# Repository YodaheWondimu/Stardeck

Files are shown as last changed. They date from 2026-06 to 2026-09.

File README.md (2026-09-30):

# Stardeck

A minimalist cyberdeck made for a software guy to learn embedded systems, electronics, and hardware design.
Also, a project made during and for Hack Club's 2026 [Stardance Challenge](https://stardance.hackclub.com/).

[Stardance Project Page](https://stardance.hackclub.com/projects/19479)

## Hero Image

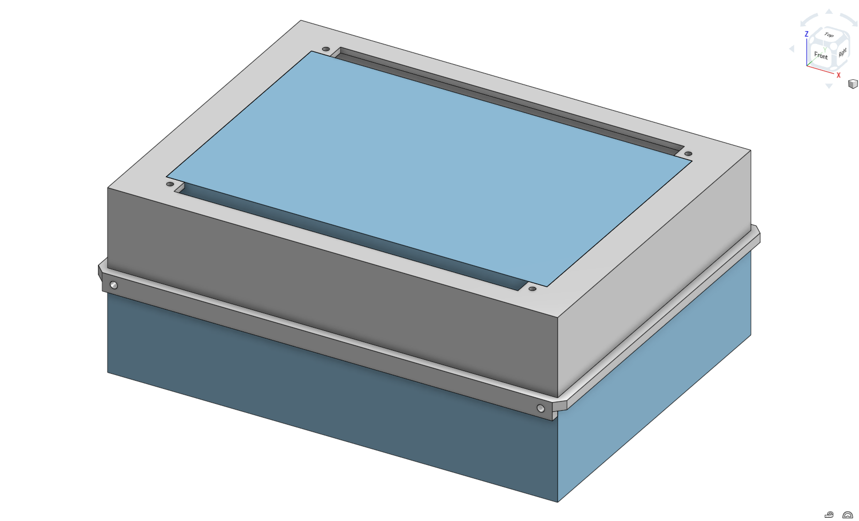
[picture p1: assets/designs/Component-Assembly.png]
Stardeck


## The Design

View the Onshape document [here!](https://cad.onshape.com/documents/8bb1ca9b7e5ac3a8ddb6398c/w/dff90e83964596d1d17b9d10/e/fb41c0251ce7e4dd570a11cb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)

## What can Stardeck do?

Once the hardware is assembled, Stardeck would be able to:
- Boot Raspberry Pi OS
- Surf the web
- Download and upload files
- Connect to external devices
- Work with a touchscreen (no mouse required!)
- Allow for further customization in the future (through the Pi's GPIO pins)

## Bill of Materials (BOM)

**Note: The Raspberry Pi 4, keyboard, and flash drive are already owned, so I currently do NOT need funding for these parts. The parts I need funding for are the ones with prices listed next to them - the display, power bank, memory card, and video cable.**

| Component | Model | Qty | Cost | Link |
|---|---|----:|-----:|---|
| Computer | Raspberry Pi 4 Model B (4GB RAM) | 1 | $0.00 | Already Owned - NOT requesting funding for |
| Display | Elecrow RC070 7-inch Touchscreen Display (1024×600) | 1 | $54.99 | [CrowPi](https://www.crowpi.cc/products/rc070-7-inch-raspberry-pi-monitor-1024x600-touchscreen-mini-hdmi-lcd-screen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) |
| Power Bank | Anker 10000mAh Portable Charger | 1 | $19.99 | [Amazon](https://www.amazon.com/Anker-Travel-Ready-Technology-High-Speed-Output%EF%BC%88Black%EF%BC%89%EF%BC%8C1pack/dp/B0D5CLSMFB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) |
| Storage | SanDisk Ultra Plus 64GB microSDXC UHS-I Memory Card | 1 | $14.00 | [Best Buy](https://www.bestbuy.com/product/sandisk-ultra-plus-64gb-microsdxc-uhs-i-memory-card/JXJ62C647Q) |
| Video Cable / Adapter | Micro HDMI to HDMI Adapter Cable (6 inch) | 1 | $3.64 | [Walmart](https://www.walmart.com/ip/Micro-HDMI-to-HDMI-Adapter-Cable-4K-60Hz-15cm-6-inch-Short-Cord-for-Raspberry-Pi-5-4-Camera-Tablet-HDTV/19994810413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) |
| Keyboard | Existing USB Keyboard | 1 | $0.00 | Already owned |
| Flash Drive | Existing 128GB USB Flash Drive | 1 | $0.00 | Already owned |

**Total Project Cost (USD): $92.62**

## How Stardeck Works

As a cyberdeck, what Stardeck has that laptops from big tech may not have is a simple digital experience. With no bloatware or ads pushed onto the user, your device is truly yours. Of course, the planned device for now is a minimum viable product focusing on what Stardeck can do to join the cyberdeck club.

The parts that'll be used consist of:
- Raspberry Pi 4 Model B
- Elecrow Touchscreen Display
- Anker Portable Charger
- microSDXC Memory Card
- microHDMI to HDMI Adapter Cable
- Keyboard
- Flash Drive

The parts will be organized together to fit into a 3D printed enclosure of my design. To understand how Stardeck works, we can look into the purposes of each part and how they interact. The Raspberry Pi was chosen to handle all of Stardeck's computing tasks because it was capable of running a dedicated OS, connecting to the outside world (Internet, Bluetooth, USB-A), and intuitively receiving power without turning Stardeck into a gaming rig. The touchscreen display from Elecrow keeps the enclosure simple with the added bonus of running Stardeck independent of a mouse. The usage of two different memory sources, the memory card and the flash drive, abstracts away logistics/"stats for nerds" for the user's sanity - the memory card can hold OS and system files for the Pi while the flash drive can hold personal files and executables for the user.

These are the parts that I'm using, but what about the part that I'm designing - the enclosure? I went with a two-piece clamshell design for its elegant ease of use. After adding alignment lips to help with nesting the top half onto the bottom shoebox-style, I continued adding physical features as necessary. For example, the mounting rails on the bottom half are the Raspberry Pi's stepstool; they keep the Pi near the middle of Stardeck so it can connect to all the other parts easily. A battery tray also makes up the bottom half to keep the battery pack from sliding all around. When I was figuring out which side to place the battery tray into, I realized how annoying it would be to nudge the battery pack under the mounting rails, so I chose the side opposite to it on the enclosure floor to save myself from crying later. As for actually keeping these parts' order, I used threaded bosses as my holes in the mounting rails, top half, and alignment lips to cooperate with screws that'll mount the Raspberry Pi, screen, and enclosure halves respectively. After months of designing/wrestling around parts I didn't have, the main lesson I've learned is that the toil of predicting and fixing hardware problems before they show themselves to you is just one step prior to the fun part I'm hoping for: getting a usable Stardeck to work IRL.

## Acknowledgements

The [Stardance Challenge](https://stardance.hackclub.com/) is what pushed me to take an idea and turn it into something unmistakably mine this summer. Go check them, and [Hack Club](https://hackclub.com/), out! This wouldn't have been possible without their guidance, support, and honest feedback.

Thanks to [HTM Workshop's KiCAD tutorial playlist](https://www.youtube.com/playlist?list=PLUOaI24LpvQPls1Ru_qECJrENwzD7XImd) for walking me through how KiCAD works. Just knowing KiCAD existed was a game changer for how I viewed the project, even if I ended up using Onshape to give my idea some shape. The big three used in my project were KiCAD for initial schematics, draw.io for architecture diagrams and notes, and Onshape for the physical CAD that got Stardeck out of the phase of "that would be nice to have. Oh well..."

**AI Usage Declaration:** I regularly used ChatGPT as a learning resource while making Stardeck, since it was able to introduce libraries to me that I wasn't familiar with, find relevant Featurescripts for certain problems in Onshape, and monitor consistency between my port map in draw.io and my modeled connections in Onshape. However, all major decisions that characterized Stardeck were made by me.

Want to learn more about Stardeck?
I've got key design notes in the [`docs`](docs) folder.
There's day-to-day progress in my [`JOURNAL`](JOURNAL.md), too!

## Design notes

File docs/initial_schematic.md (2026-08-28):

# Initial Schematic

_Note: This is simply a system schematic to understand how components in the cyberdeck will interact with one another, paired with a packaging study to understand how much space each part takes up in our chosen arrangement. Nothing too crazy for now._

With ideation for designs in place, it's easy to jump into the technical details first. However, that's for some time later. This document focuses on the abstracted interactions between the power, the Raspberry Pi (I chose to go with a Raspberry Pi 4B), the screen, and the keyboard. After we figure out these interactions, we can take note of dimensions and (hopefully?) get a physical representation of our current parts onto Onshape so we can design a starting case. The starting question was:

**What parts will Stardeck consist of, and how do they interact with one another?**

Here's what I managed to identify about the major subsystems and their relationships through investigation.

## Questions Answered
The cyberdeck consists of four primary subsystems:
- Power
- Computer
- Input
- Output

## System Schematic (acting as our initial plan)
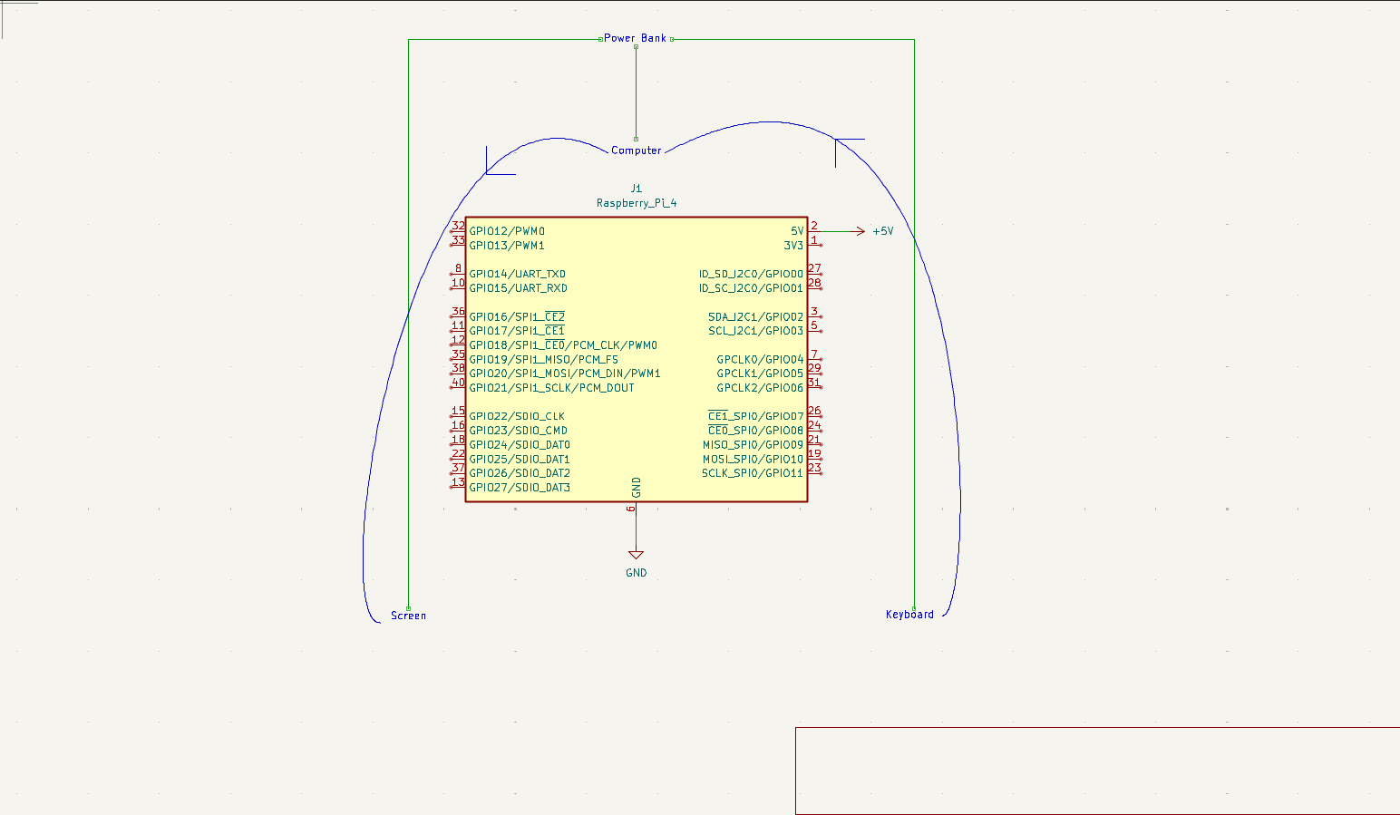
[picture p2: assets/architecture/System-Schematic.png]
System Schematic


## Descriptions:
- The power subsystem provides energy to all the other subsystems. This is the cornerstone of Stardeck.
- The computer acts as the central controller. It manages the actions of input and output.
- The keyboard serves as the primary input device. Makes sense - typing will be the main source of input as other input sources (coming through extra USB ports for other devices) can be figured out later, especially if the display is touchscreen.
- The display serves as the primary output device. It shows you what's going on.

## Open Questions
- Which display to buy?
- How large should the battery be?
- Integrated keyboard or external keyboard?
- Approximate enclosure dimensions?

I was able to follow along with this intuitively. After this, I looked into many cyberdeck designs available publicly (r/cyberdeck was particularly helpful) and decided on a compact, tablet-like cyberdeck.

This will consist of a screen inserted into the front face, with the Raspberry Pi and power bank mounted inside the shelled enclosure behind it. This is the most efficient design to aim for as of right now since we're only aiming to boot it up for this version. In future versions, we can make the screen rotate to face you laptop-style for a better feel.

## Packaging Study Findings

These were the initial, "best guess" dimensions inside the placeholder based on guesswork:

(All 3D dimensions listed are in the form length x width x height.)

- **Case**: 230 mm x 160 mm x 40 mm, 
_(with a cut-out opening on the top face to make room for the inserted screen.)_

- **Screen**: 200 mm x 120 mm x 15 mm

- **Raspberry Pi 4B**: 90 mm x 60 mm x 25 mm

- **Power Bank**: 110 mm x 70 mm x 20 mm

The initial screen placeholder was too big to match the intended size.

The original placeholder measured approximately 200 mm × 120 mm, resulting in a diagonal of ~233 mm (~9.2 inches). However, the intended display size is 7 inches. The placeholder was revised to:

- **Screen (7")**: 155 mm x 87 mm x 15 mm,

yielding a diagonal measurement consistent with a 7-inch display.

This change made me more conscious about lowering the enclosure footprint in other ways, too, so I looked into the accuracy of the rest of the designs.

The case size appears sufficient to fit all components based on the placeholder assembly, since everything fit neatly inside of it (or inserted onto it, in the screen's case). The Raspberry Pi placeholder was intentionally sized slightly larger than the actual board to account for cable clearance, tolerances, and mounting considerations. As for the battery pack, though, I haven't selected anything specific just yet. Because of this, the battery pack's placeholder dimensions are based on estimates and should be updated once a specific battery model is selected. Speaking of selection, note that the battery dimensions are preliminary estimates based on a typical 10,000 mAh USB power bank and should be updated after choosing our final power source (something rechargeable from Anker, perhaps).

With these in mind, here was the placeholder assembly used for the packaging study:

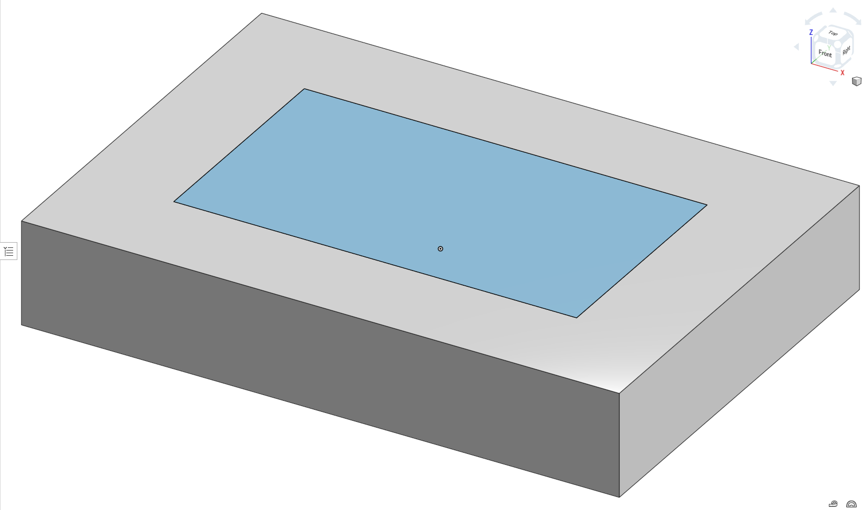
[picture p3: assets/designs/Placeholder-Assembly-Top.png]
Placeholder Assembly (Top)


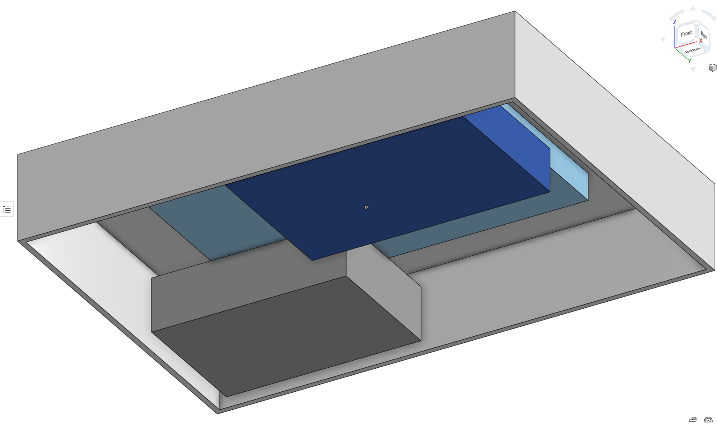
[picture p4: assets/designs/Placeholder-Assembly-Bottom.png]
Placeholder Assembly (Bottom)


So far, the parts we will be using seem to interact with each other clearly and fit into one coherent assembly. For next steps, we'll determine how the selected components will interface with one another and refine this system diagram into a more detailed schematic.

God bless you,

^ Yodahe

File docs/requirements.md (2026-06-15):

# Requirements

These are what the Stardeck needs before considered complete.
After these are fulfilled, we can always improve it then, but these are our priorities.
Afterwards, we can decorate it, give it a cooler design, etc

## Functional Requirements
- Must boot Linux
- Must run Python
- Must be battery-powered
- Must have keyboard input

## Non-Functional Requirements
- Portable
- Durable enough for backpack use
- 3D printable

## Constraints
- Student budget (can't spend too much on this)
- First cyberdeck (haven't done much hardware work before)
- Limited electronics experience (Arduino starter kit, that's it)

## Success Criteria

Stardeck v0.1 is considered complete when:

- Linux boots successfully
- Python programs can be executed
- Device operates from battery power
- Keyboard input functions correctly
- Device can be transported in a backpack

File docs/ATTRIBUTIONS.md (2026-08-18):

# CAD Attributions

Some component models used in Stardeck's detailed assembly were made by third parties and are included as reference geometry for dimensions, packaging, and assembly.

## Raspberry Pi 4 Model B

- **Model:** Raspberry Pi 4 Model B
- **Creator:** [Pyro_Industries](https://www.printables.com/@pyro)
- **Source:** https://www.printables.com/model/727545-raspberry-pi-4
- **License:** CC0 / Public Domain
- **Use:** Reference geometry for the Raspberry Pi 4 Model B in Stardeck's detailed assembly.
- **Modifications:** None

## 7-inch Display

- **Model:** Elecrow RC070 7-inch Touchscreen Display (1024x600)
- **Creator:** Elecrow
- **Source:** https://www.crowpi.cc/products/rc070-7-inch-raspberry-pi-monitor-1024x600-touchscreen-mini-hdmi-lcd-screen
- **License:** Not stated on the source page
- **Use:** Reference model used to verify display placement and enclosure clearances.
- **Modifications:** Added mounting holes matching those of the real component to coordinate screen mounting with the top half of the enclosure.

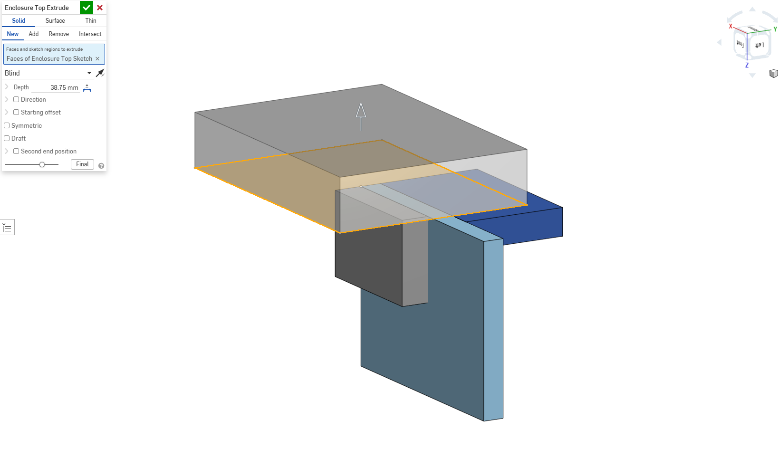
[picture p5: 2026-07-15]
assets/designs/Enclosure-Top-Extrude.png

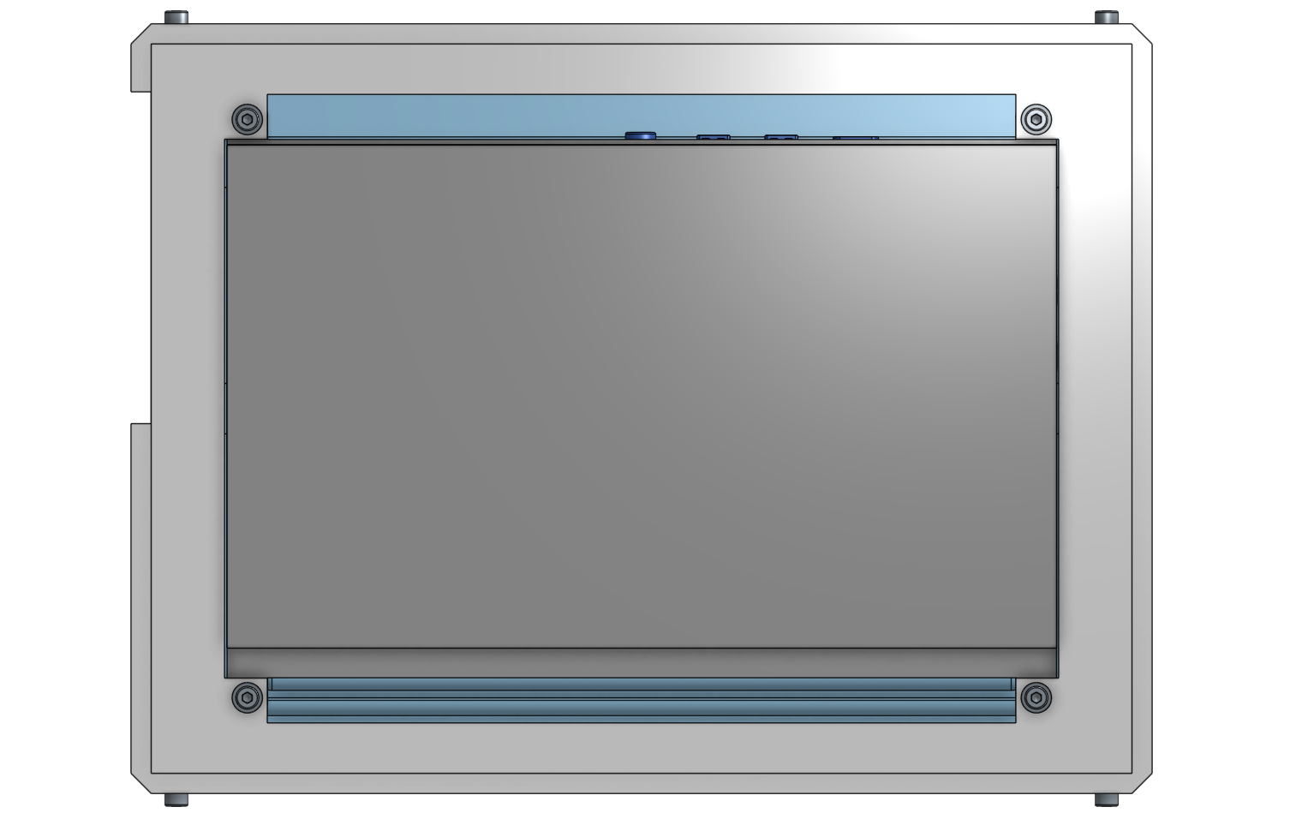
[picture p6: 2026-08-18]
assets/designs/Revised-Top-View.png

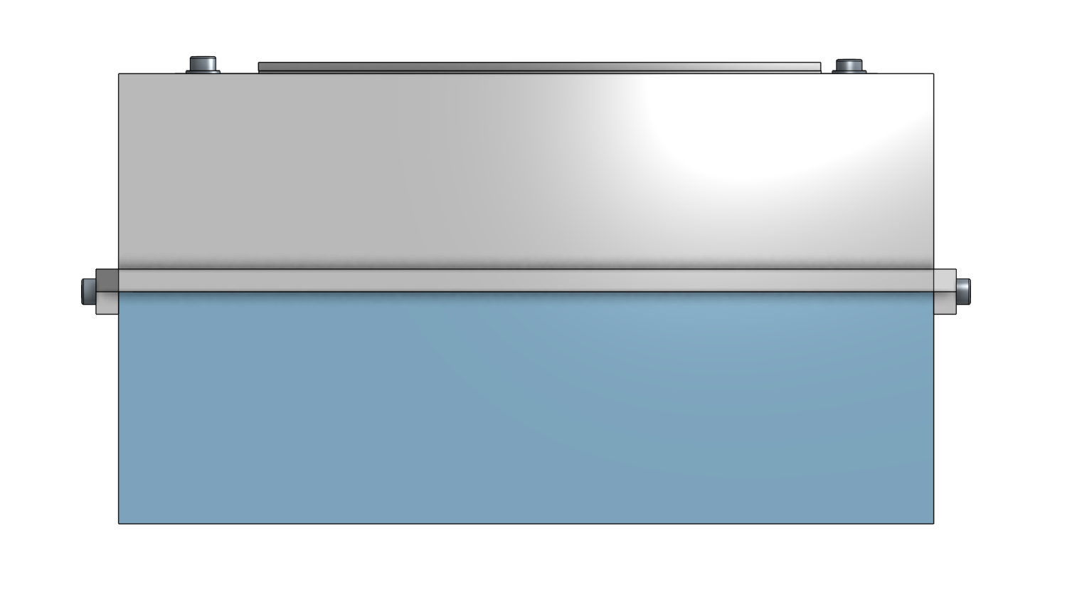
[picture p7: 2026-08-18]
assets/designs/Revised-Side-View.png

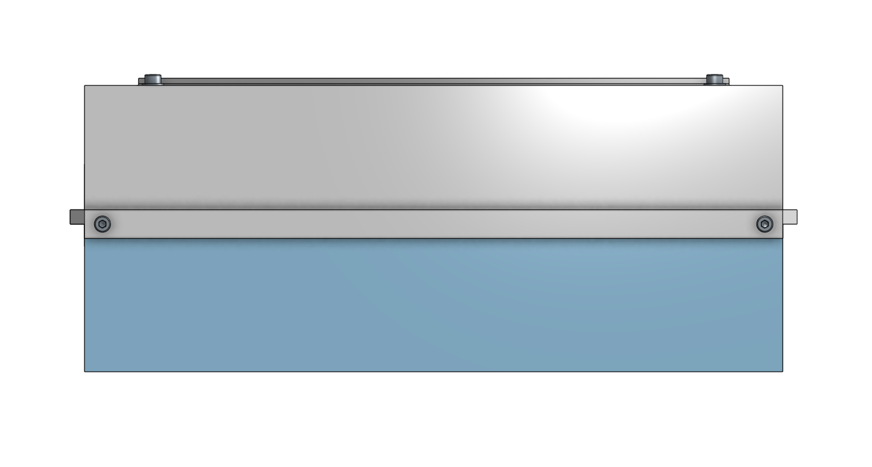
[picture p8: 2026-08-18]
assets/designs/Revised-Front-View.png

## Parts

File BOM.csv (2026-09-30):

Component | Model | Qty | Cost | Link
Computer | Raspberry Pi 4 Model B (4GB RAM) | 1 | 0.00 | Owned - NOT requesting funding for
Display | Elecrow RC070 7-inch Touchscreen Display (1024x600) | 1 | 54.99 | https://www.crowpi.cc/products/rc070-7-inch-raspberry-pi-monitor-1024x600-touchscreen-mini-hdmi-lcd-screen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
Power Bank | Anker 10000mAh Portable Charger | 1 | 19.99 | https://www.amazon.com/Anker-Travel-Ready-Technology-High-Speed-Output%EF%BC%88Black%EF%BC%89%EF%BC%8C1pack/dp/B0D5CLSMFB
Storage | SanDisk Ultra Plus 64GB microSDXC UHS-I Memory Card | 1 | 14.00 | https://www.bestbuy.com/product/sandisk-ultra-plus-64gb-microsdxc-uhs-i-memory-card/JXJ62C647Q
Video Cable / Adapter | Micro HDMI to HDMI Adapter Cable (6 inch) | 1 | 3.64 | https://www.walmart.com/ip/Micro-HDMI-to-HDMI-Adapter-Cable-4K-60Hz-15cm-6-inch-Short-Cord-for-Raspberry-Pi-5-4-Camera-Tablet-HDTV/19994810413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
Keyboard | Existing USB Keyboard | 1 | 0.00 | Owned
Flash Drive | Existing 128GB USB Flash Drive | 1 | 0.00 | Owned
Total Project Cost (USD) |  | 1 | 92.62

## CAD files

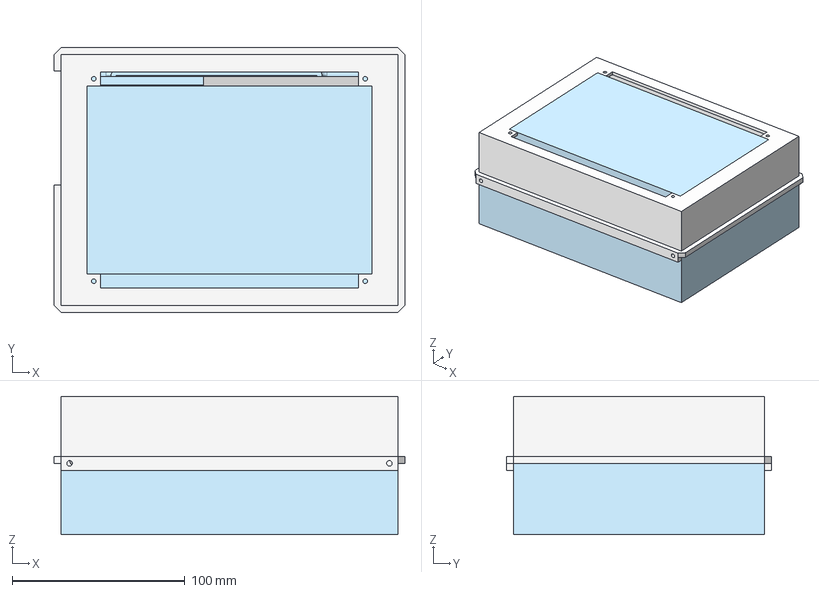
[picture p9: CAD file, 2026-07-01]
cad/Component-Assembly.step
203.0 x 153.0 x 80.0 mm

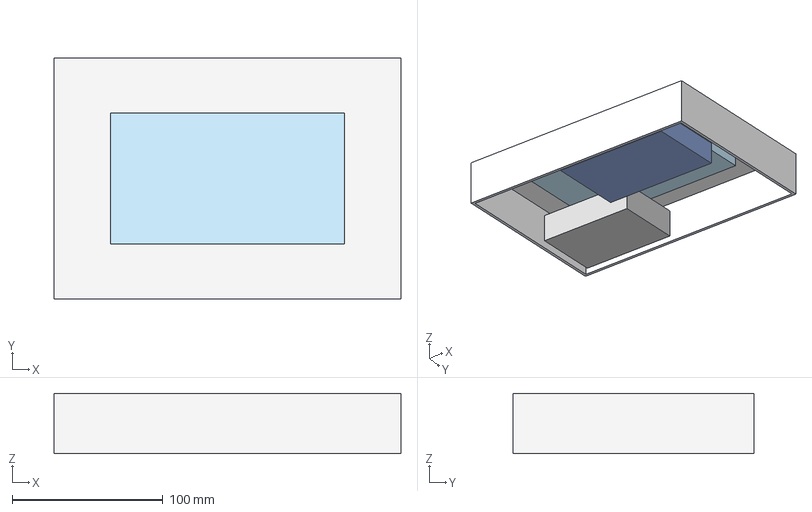
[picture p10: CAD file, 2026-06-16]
cad/Placeholder-Assembly.step
230.0 x 160.0 x 40.0 mm
Battery Block
Screen Block
Pi Block
Enclosure Base

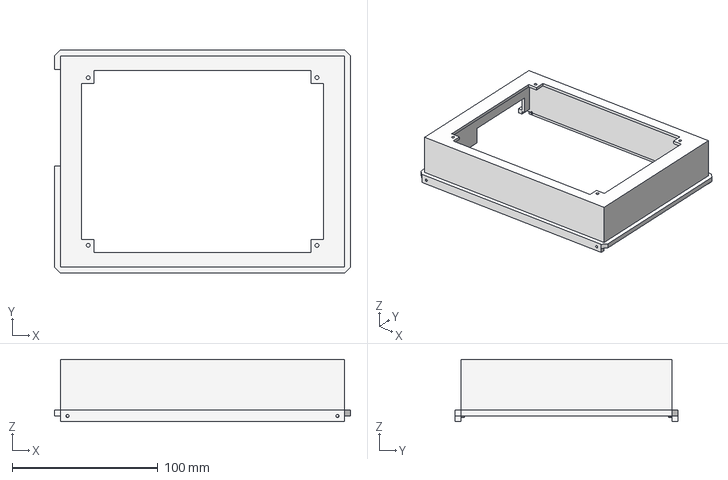
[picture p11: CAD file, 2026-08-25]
cad/Enclosure-Top-Revised.step
203.0 x 153.0 x 42.8 mm

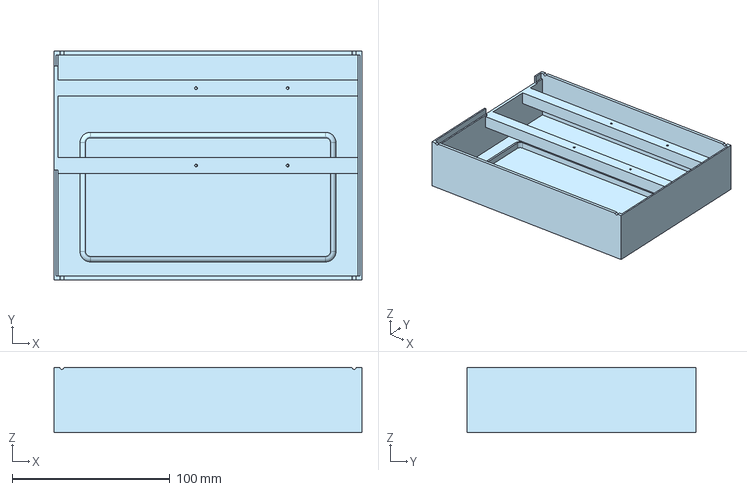
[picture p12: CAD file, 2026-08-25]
cad/Enclosure-Bottom-Revised.step
195.0 x 145.0 x 41.2 mm

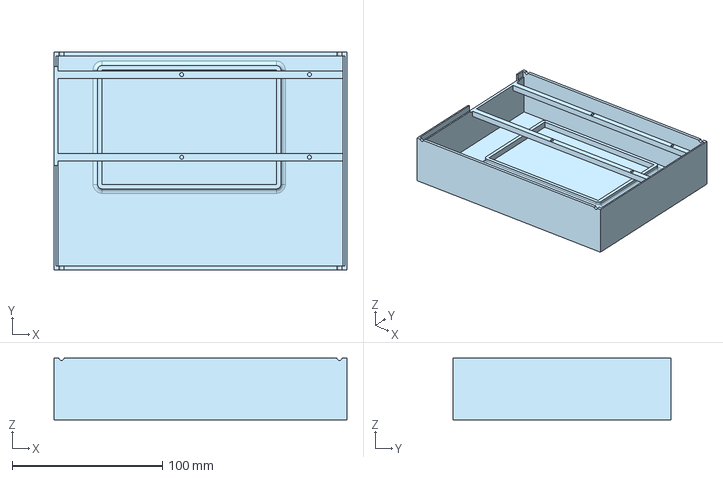
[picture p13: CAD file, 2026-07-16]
cad/Enclosure-Bottom.step
195.0 x 145.0 x 41.2 mm

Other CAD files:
cad/Enclosure-Top.step
cad/Component-Assembly.stl
cad/Enclosure-Bottom-Revised.3mf
cad/Enclosure-Bottom-Revised.stl
cad/Enclosure-Bottom.3mf
cad/Enclosure-Bottom.stl
cad/Enclosure-Top-Revised.3mf
cad/Enclosure-Top-Revised.stl
cad/Enclosure-Top.3mf
cad/Enclosure-Top.stl
cad/Placeholder-Assembly.stl

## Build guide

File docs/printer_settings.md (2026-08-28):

# Printer Settings

Hey there! This document is a place to store my print settings. Due to the open-source nature of Stardeck, you can already find those by looking in [`../assets/designs`](../assets/designs/), where you'll see the `.3mf` project files used to print the enclosure. This document is your reference point if a slicer import does not preserve every setting, so if you're here after that happened, you're welcome!

## Printer

**Printer model:** Creality Hi

**Nozzle diameter:** 0.4 mm

## Filament

**Material:** PLA

**Nozzle temperature:** 210 °C (default profile)

**Bed temperature:** 60 °C

**Cooling:** Default PLA profile

## Print

**Slicer:** Creality Print 7.x

**Layer height:** 0.2 mm

**Initial layer height:** 0.2 mm

**Wall loops:** 2

**Top shell layers:** 4

**Bottom shell layers:** 4

**Infill density:** 15%

**Sparse infill pattern:** Rectilinear

**Internal solid infill pattern:** Monotonic

**Outer wall speed:** 200 mm/s

**Inner wall speed:** 300 mm/s

**Sparse infill speed:** 270 mm/s

**Internal solid infill speed:** 250 mm/s

**Top surface speed:** 200 mm/s

**Travel speed:** 300 mm/s

**Initial layer speed:** 50 mm/s

**Seam position:** Aligned

**Supports:** Enabled

**Support style (Tree):** Default

**Build plate:** Smooth PEI (High Temperature Plate)

**Build plate adhesion (Brim, etc.):** None

## Helpful Tips

When printing each shell, orient your print so that the biggest face is touching the printbed. (Print orientation photos demonstrate this below.) For the bottom shell, keep the bottom-side face down, and for the top shell, keep the screen-side face down.

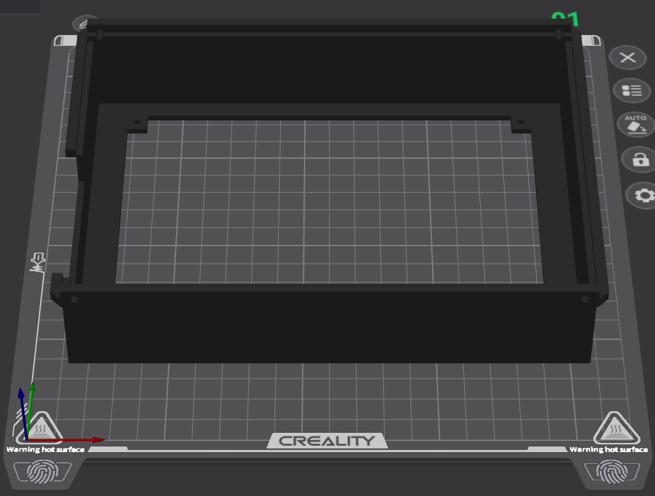
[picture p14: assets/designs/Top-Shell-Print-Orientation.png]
Print Orientation (Top)


- Approximate Print Time (Top Shell): 4 Hours, 48 Minutes
- Filament Usage (Top Shell): ~102.74 g

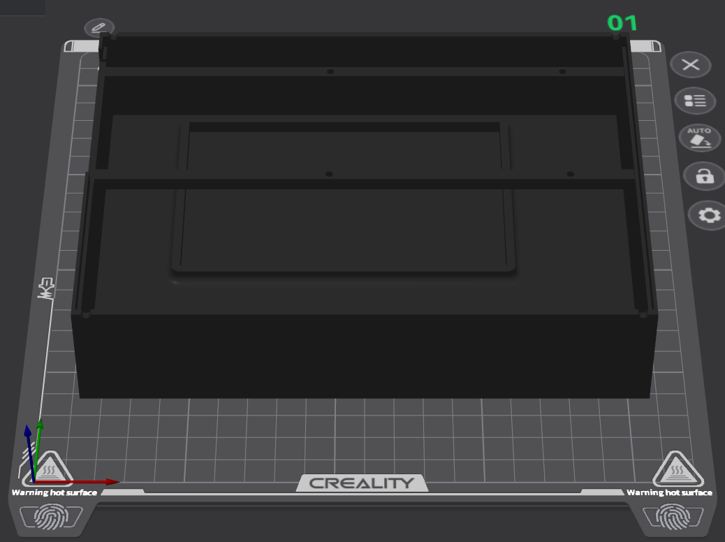
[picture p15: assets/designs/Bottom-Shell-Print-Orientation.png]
Print Orientation (Bottom)


- Approximate Print Time (Bottom Shell): 4 Hours, 36 Minutes
- Filament Usage (Bottom Shell): ~144.18 g

After setting up these orientations, it's recommended to add automatic tree supports to support the floating cantilever (from the mounting rails) in the bottom shell and the overhanging alignment lips in the top shell.

If you're using the included `.3mf` project files, no need to worry - these orientations and supports should already be preserved.

## Note

The accompanying `.3mf` project files preserve the print orientation, support placement, and slicer settings used to produce the printable models in this repository, including the first physical enclosure documented in [`../JOURNAL.md`](../JOURNAL.md).

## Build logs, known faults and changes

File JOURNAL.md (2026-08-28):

# JOURNAL

Welcome to the JOURNAL! This document holds the timeline, decisions, and designs that have trademarked the work I've put into Stardeck thus far. Here are the summaries from each date.

## 2026-06-15
This is where it starts. The project in question was a cyberdeck, we knew that much for sure. But what takes me to a cyberdeck exactly? What are the goals? What's the minimum possible device that would count as a cyberdeck? Would this be too strenuous for a self-declared software guy to do? There was only one way to find out.

To start doing the thing, I wanted to at least know what the goals were. I reasoned the goal into this: _Build the ugliest possible cyberdeck and submit it to Stardance, including what I learned from building it._ Probably not the nicest maker if I'm calling my own projects ugly, but the idea is that aesthetics and twist-giving, defining features can wait until I can actually figure out how to get a cyberdeck booting first. We can add more features and aesthetics later, but something that boots is our main priority, similar to how you need to know how to make a cheese pizza before making one with toppings. In other words, the goal is to get a cyberdeck working, and the Minimal Viable Product (MVP) is a cyberdeck that works.

Oh, I also chose what I'll use for the cyberdeck's brain - a Raspberry Pi. The specific model will be a Raspberry Pi 4B with 4GB of RAM, and it packs a lot of computing efficiency compared to what I used to think Single-Board Computers could do. This thing can boot an OS, interact with components, connect using Internet and Bluetooth, and more - plus, the Pi is a clear favorite of first-time cyberdeckers (whatever you call them).

_TL;DR:_
- Defined project goals and MVP.
- Selected Raspberry Pi as the compute platform.

**Time Spent This Session: 0 Build Hours (Research Only)**

## 2026-06-16
KiCAD is a tool that allows you to create electrical schematics for components such as custom Printed Circuit Boards (PCBs). I like to think of it as Onshape, but for electricity. One good thing that comes from this is that I'm able to use the basics to visualize components and pins at the very least, even if I don't use a PCB for the initial cyberdeck. Wiring concepts were coming through, and I got to thinking about what makes a cyberdeck a cyberdeck.

Initial Concept

Okay, so about KiCAD...it was helpful, but not exactly the tool I needed. KiCAD is the tool that guides you through schematics, PCBs, circuits, and other feats of electrical engineering. That's great and all, but it wasn't exactly the thing that I was going for all the way because my component connections were occurring on the component level rather than the electrical level. I knew that I would have to plan out how every component would fit together, and so I started an initial packaging study exclusively using a placeholder for only a few parts. This helped me think of the general shape of the cyberdeck before committing to working on more of the packaging study, and I went with a tablet-style cyberdeck for the first iteration.

Placeholder Assembly (Top)

Placeholder Assembly (Bottom)

With these in place, I published my very first devlog to Stardance to hear what others thought so far. I tried to write in a formal tone like I tend to do for replicable public work, but we'll see how the tone of voice fits in.

_TL;DR:_
- Learned KiCAD basics.
- Drew initial wiring concepts on KiCAD.
- Determined a custom PCB wasn't needed for v1.
- Posted Devlog #1 to Stardance.

**Time Spent This Session: ~1.5 Hours**

## 2026-06-17
I had to figure out how I was going to plan everything out if KiCAD wasn't necessarily my best bet. That's when I was looking into tools online and found draw.io - an open-source drawing platform that allows you to create diagrams for development workflows. This really fit what I was going for, and after learning the basics, I worked through the first few elements, which represented the components of Stardeck.

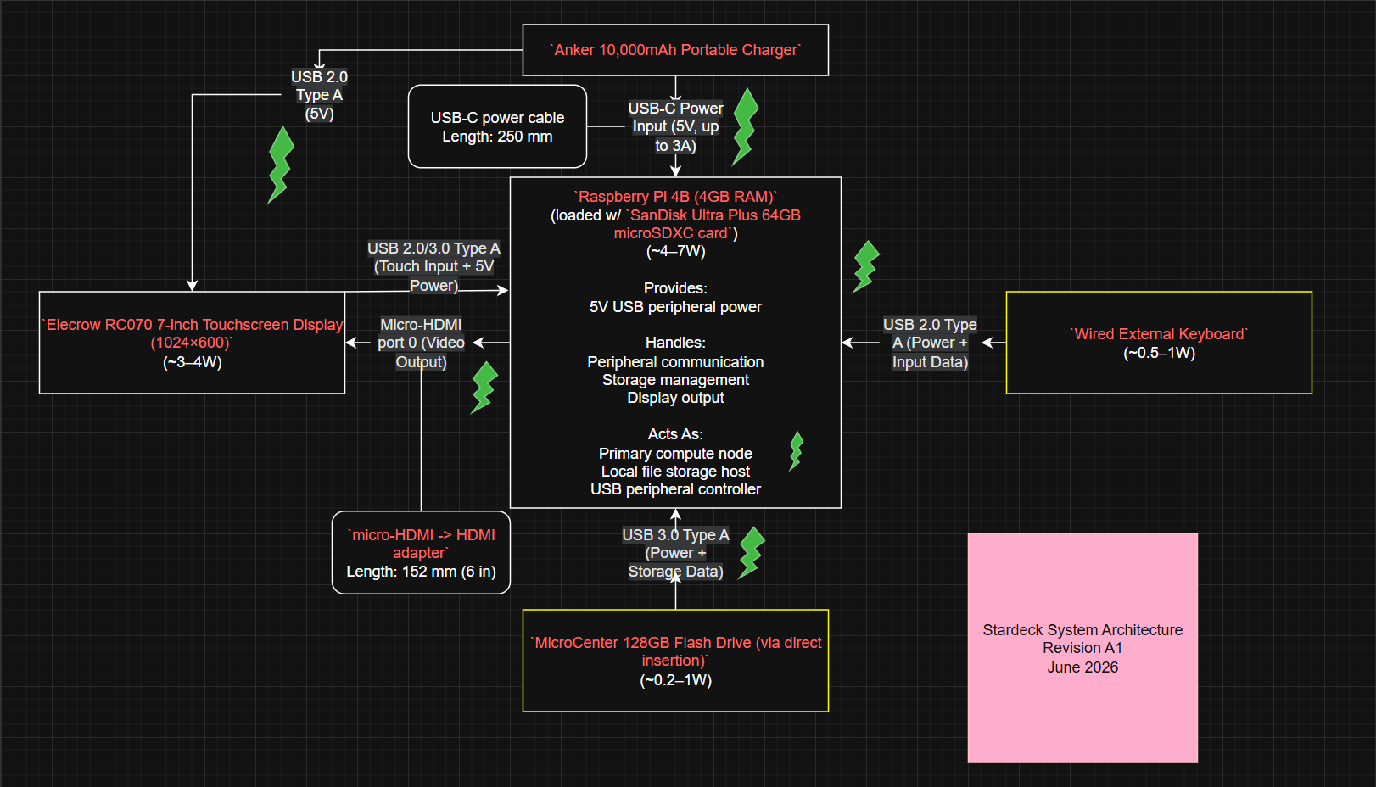
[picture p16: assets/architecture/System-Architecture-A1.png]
Wiring Diagram Revision A1


_TL;DR:_
- Learned how to use draw.io for diagrams.
- Started making a wiring diagram with draw.io.

**Time Spent This Session: ~0.5 Hours**

## 2026-06-23

Yeah, my tone of voice wasn't hitting the right notes with the audience I had. My devlog seemed so distant from the audience compared to others I've seen on Stardance. Some even considered the devlog to be AI writing, even though that was far from the truth. I was confused. If everyone saw my work right there, why did it still seem like a robot was talking to them? That's when I realized that seeing my work wasn't enough when that was all they could see. My audience wanted to hear about the journey and the steps in between, not just the ending. That's when I committed to keeping future devlogs story-focused so that I wouldn't receive any doubts as to if I was the one on the keyboard.

When looking through my display options, I needed something that would have enough functionality to pack into a cyberdeck with the goal of making it work. On top of that, I later realized that my display also needed to boot with everything else. Adapters should be included if necessary, our port maps should align with our long-term goals, and our screen had to be mountable. With these in mind, I chose a 7-inch touchscreen display from Elecrow, which supported the Raspberry Pi and could fit into the enclosure I had in mind.

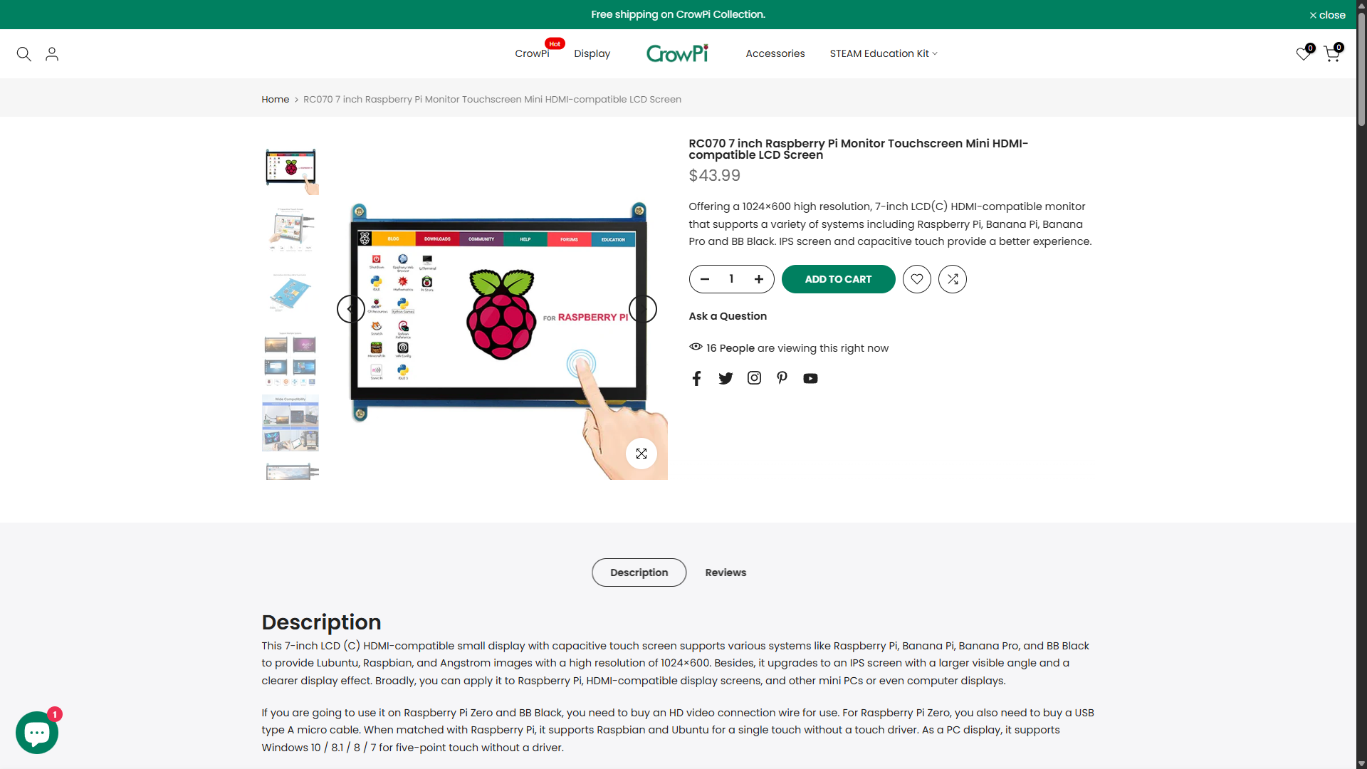
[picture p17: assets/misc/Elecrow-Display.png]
Elecrow Display


I used these same design ideas for starting my Bill of Materials (BOM) which can tell Hack Club which parts I need when it's time to get funded. I was able to pick out essentials such as a MicroSD card (system storage), a power bank/battery (distributes power to everything else), and more.

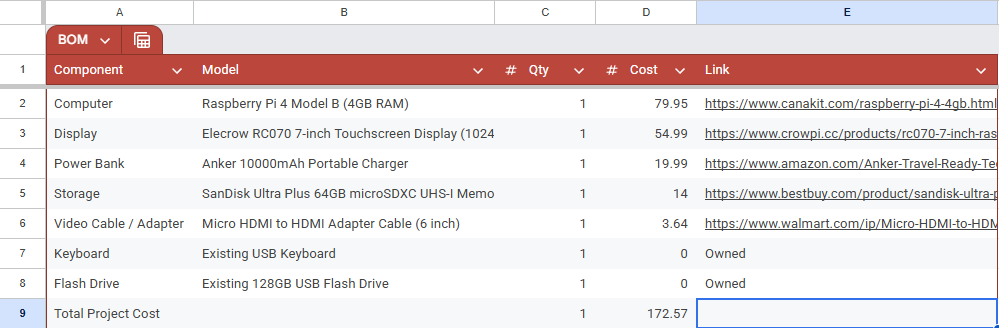
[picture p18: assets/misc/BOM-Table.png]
Bill of Materials


Another great thing that came with finding these components online was that they came with dimensions that reflected just how long, wide, or tall something was, which was bound to help me as I set out to gather info that may be useful for a packaging study.

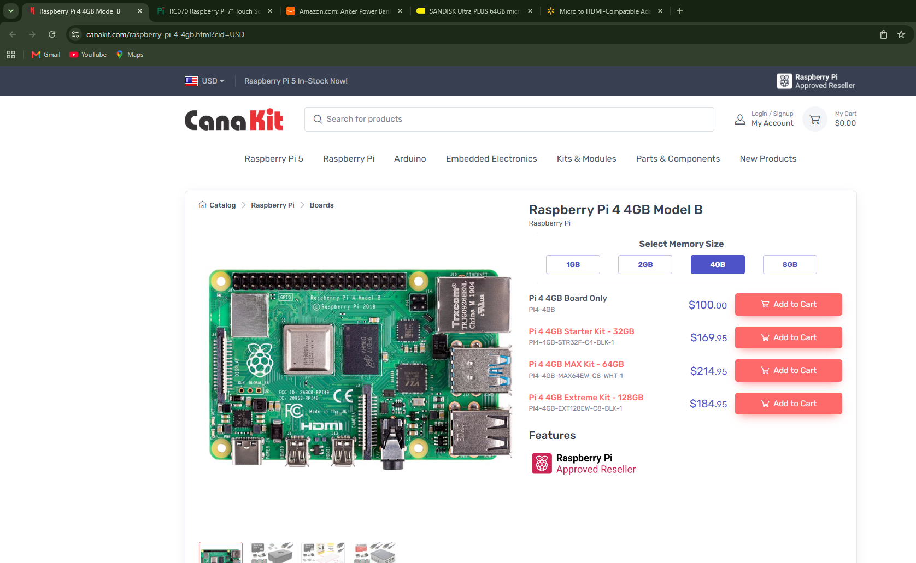
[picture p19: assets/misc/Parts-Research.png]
Researching Parts


_TL;DR:_
- Reworked my devlog writing style.
- Compared display options.
- Started BOM.
- Estimated component dimensions.

**Time Spent This Session: ~1.5 Hours**

## 2026-06-24

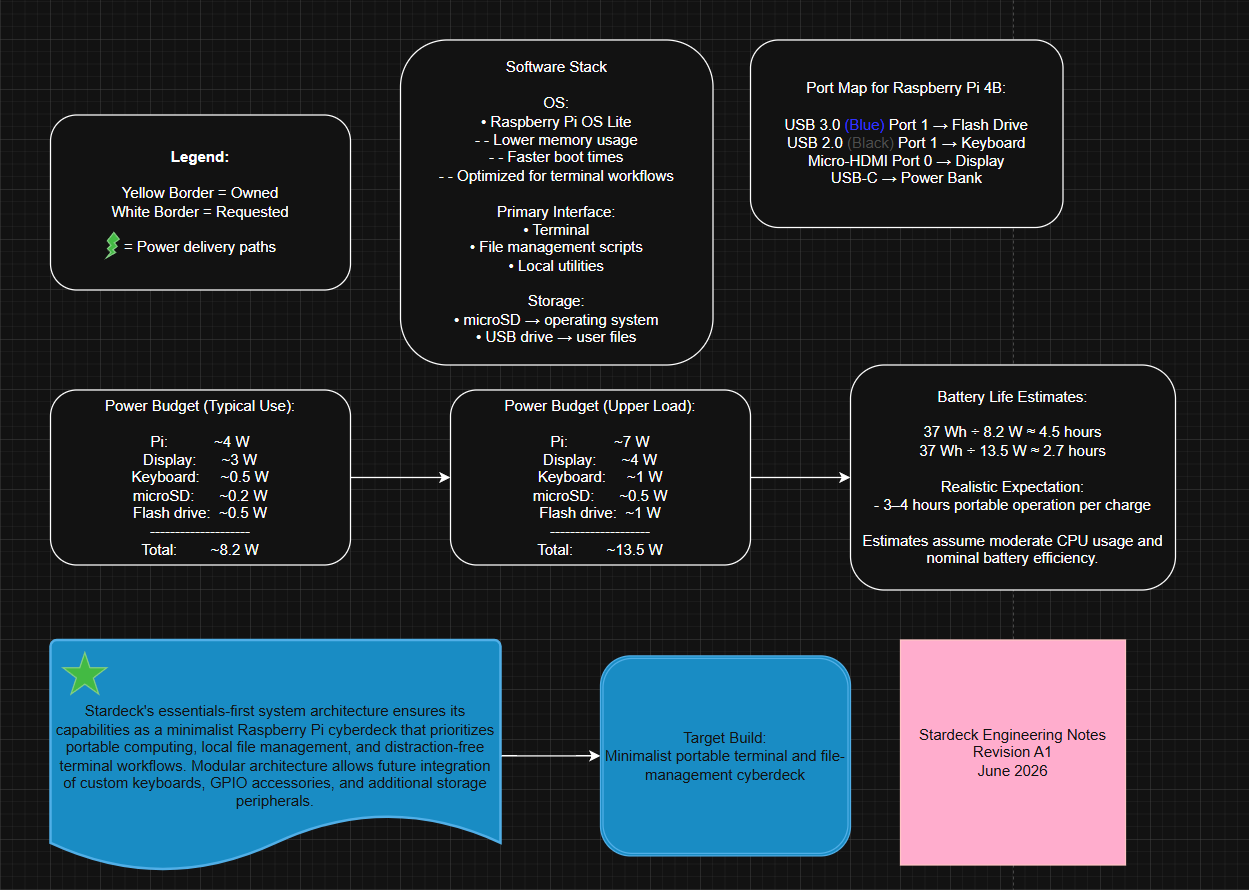
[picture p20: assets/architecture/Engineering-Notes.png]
Engineering Notes


Time for the real packaging study. These are involving parts that should work together surprisingly well if the wiring diagram stays true to its word.

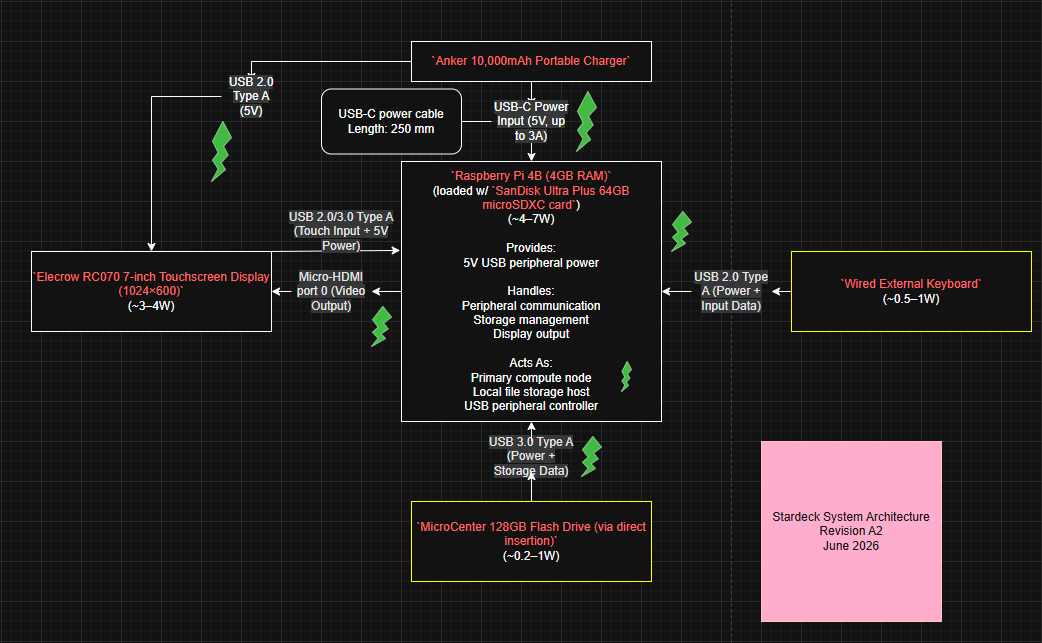
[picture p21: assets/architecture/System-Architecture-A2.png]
Wiring Diagram Revision A2


I started by modeling a few of the individual parts - screen, enclosure, Pi, and more. Luckily, the model's didn't need to have too much time put into them during the packaging study because all I needed to do was model each part as a rectangular prism of the same dimensions and model around that. Once my parts were accounted for, I used the "simple" component models to choose how big my enclosure needed to be. This was a big tradeoff to account for in the project because I wanted to have enough space for every component, but I didn't want to waste filament or create something bulky that doesn't fit the portable size requirement I had in mind.

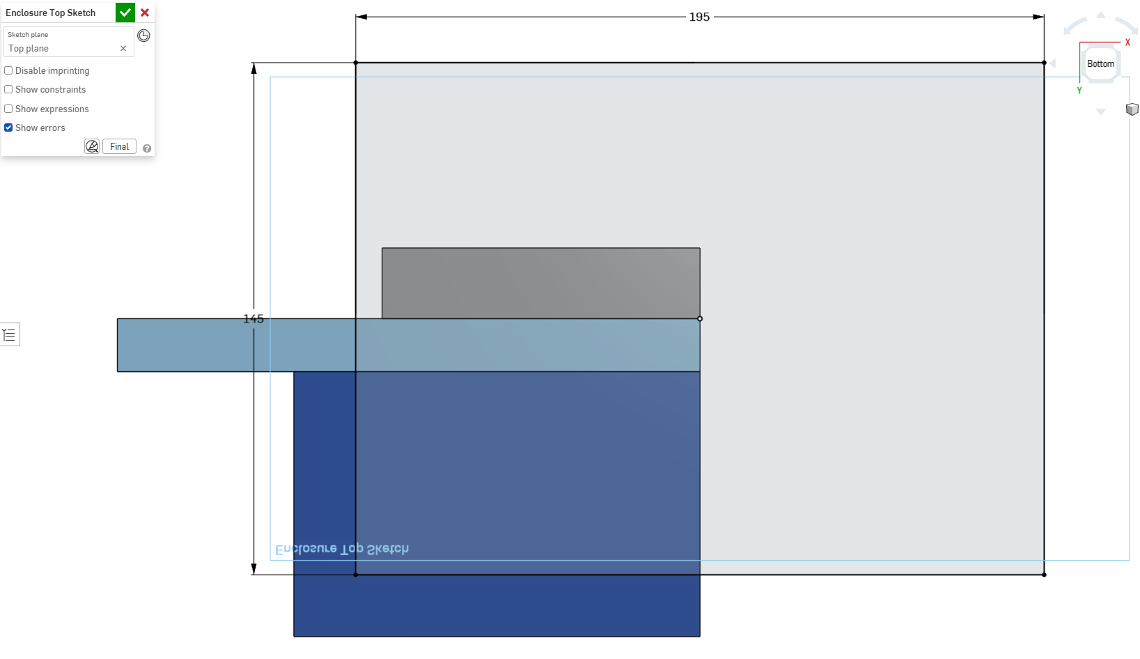
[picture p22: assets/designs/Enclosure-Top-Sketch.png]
Enclosure Length and Width


The enclosure sizing I came up with was great - 145 mm by 195 mm, with a depth of 38.75 mm. I also shelled out one of the faces to create 2.5 mm walls and cut out an opening for the display to sit in. After a lot of thought into how the system would act, it was time to figure out how the system should look.

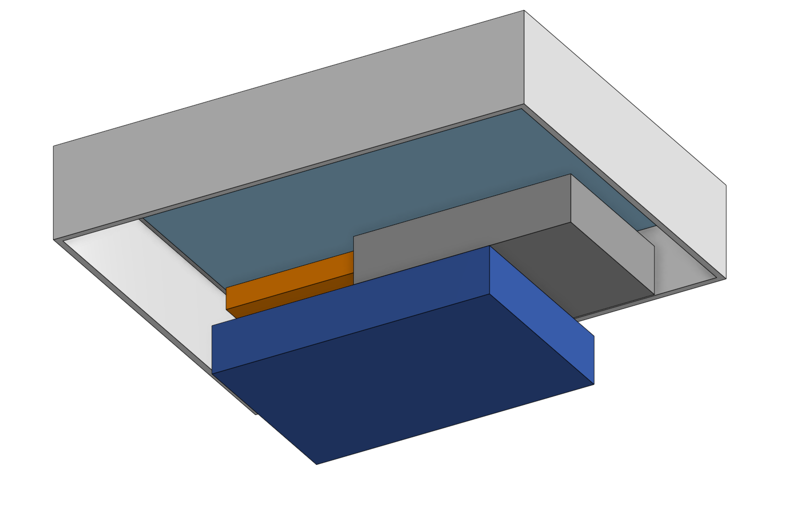
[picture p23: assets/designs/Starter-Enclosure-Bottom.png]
Starter Enclosure (Bottom)


_TL;DR:_
- Began packaging study in Onshape.
- Created simplified component models.
- Tested enclosure sizing.

**Time Spent This Session: ~0.5 Hours**

## 2026-06-28

My design was coming together. I modeled other parts such as my existing USB flash drive to provide additional storage to the user and cables that would depict possible cable routes from part to part. Once I got the internal parts done, I was thinking to myself about how every part would be physically built, until I realized that that would be close to impossible. The reason for this was that my enclosure was essentially just a plastic box with the lid missing. That's when I went through some decision-making to choose the enclosure that would solve this problem, highlighted below as one of my design decisions.

After the decision was made, I settled on a clamshell design that utilized two shells, top and bottom, to make up two different halves of the enclosure.

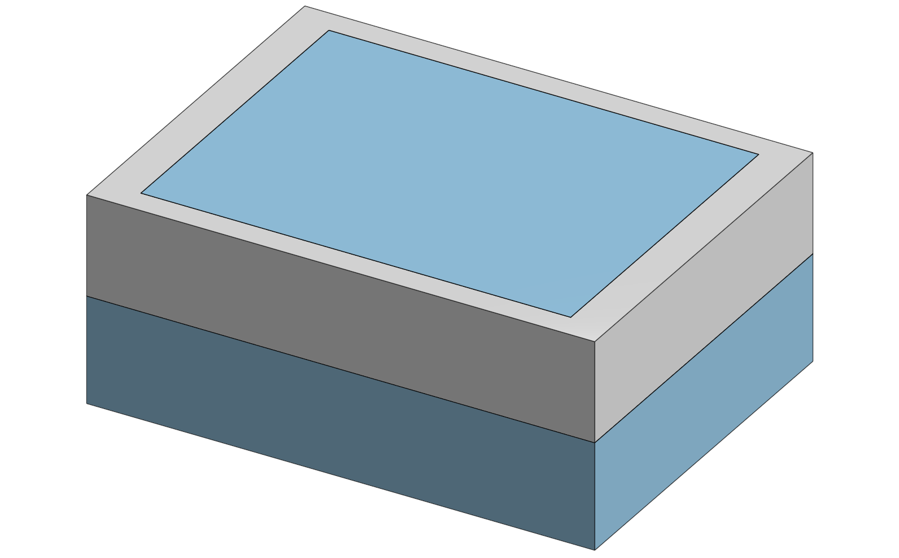
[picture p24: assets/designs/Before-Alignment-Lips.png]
Starter Clamshell


Complemented by alignment lips to keep the halves level with each other when screwing them together later, I had a real design coming up. The next real objectives were to turn my design into something that others could understand, since some parts of my enclosure still seemed like they could use more documentation.

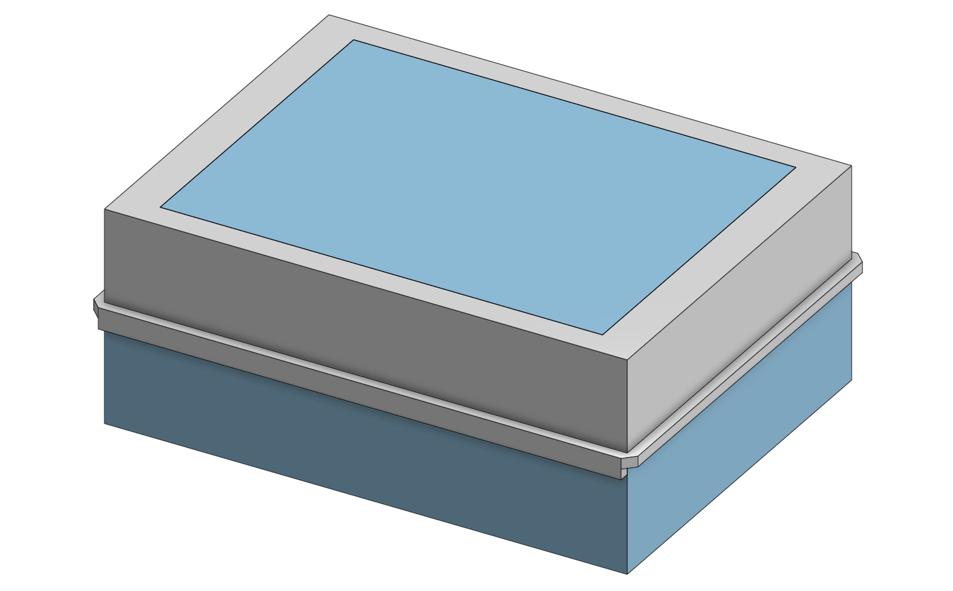
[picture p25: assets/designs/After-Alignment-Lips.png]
Alignment Lips


Furthermore, it's not like the Raspberry Pi was going to levitate in the real build. After understanding that the Pi doesn't come with flying powers, I designed simple mounting rails thanks to the design decision outlined at the bottom, which served as a working solution. I also knew of the Raspberry Pi's mounting capabilities (such as M2.5 screw holes in its corners) and how those capabilities would work well with the mounting rails in the long run.

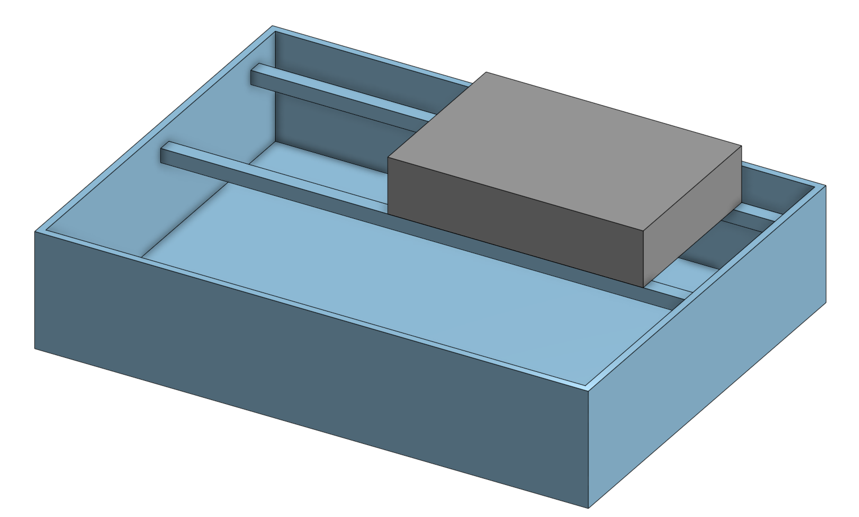
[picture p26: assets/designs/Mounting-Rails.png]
Mounting Rails


_TL;DR:_
- Switched from a one-piece enclosure to a clamshell design.
- Added alignment lips after evaluating assembly.
- Added mounting rails to support the Pi.

**Time Spent This Session: ~1.5 Hours**

## 2026-06-29

Just some polish to make things easier later. I checked over part sizes, compared them to the real components, and looked through how I could keep them in place according to what I could find online about each part. This let me learn lots of neat features about each of my parts. For example, why is the size of the screen diagonal about 8 inches when Elecrow says the screen diagonal is 7 inches? The answer: border features. The screen came with features on the border such as mounting holes and ports that required the actual diagonal measured across the surface in Onshape's perspective to be bigger than that of the screen only. Most, but not all, of that face belongs to what will actually be displayed. Nuances like this were picked up well, but apart from the research, many tweaks were made in sizing and positioning to make assembly easier later, with the main tweak being a battery tray. Another design decision below walks you through how I chose my battery mounting method, and the battery tray won over mounting straps because of its simplicity and intuition; it's like putting square pegs into square holes.

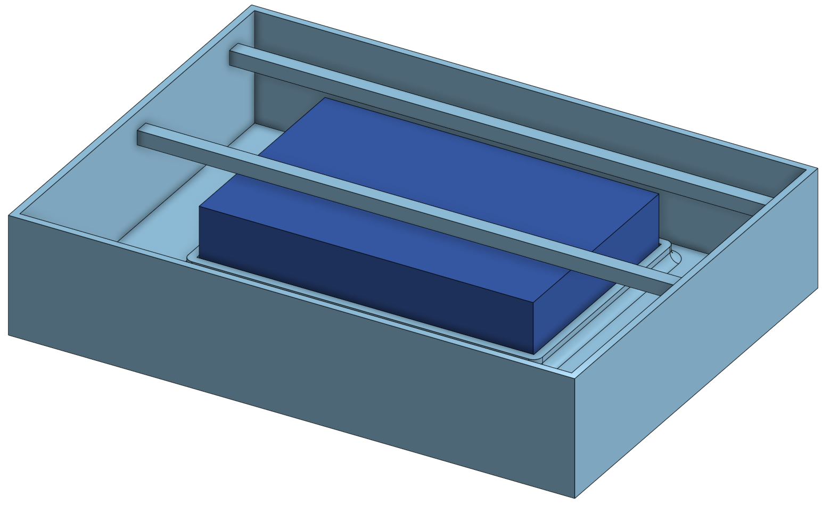
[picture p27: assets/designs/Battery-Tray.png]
Battery Tray


_TL;DR:_
- Polished wiring presentation quirks at the assembly level.
- Added battery tray to keep the battery stable.

**Time Spent This Session: ~0.5 Hours**

## 2026-06-30

Wait, so the parts _don't_ attach by themselves? I thought so. Good thing I thought of adding screw holes to anywhere that keeping parts from falling or sliding really mattered. I added screw holes in both enclosure halves to keep internals stable once I have the finished build,

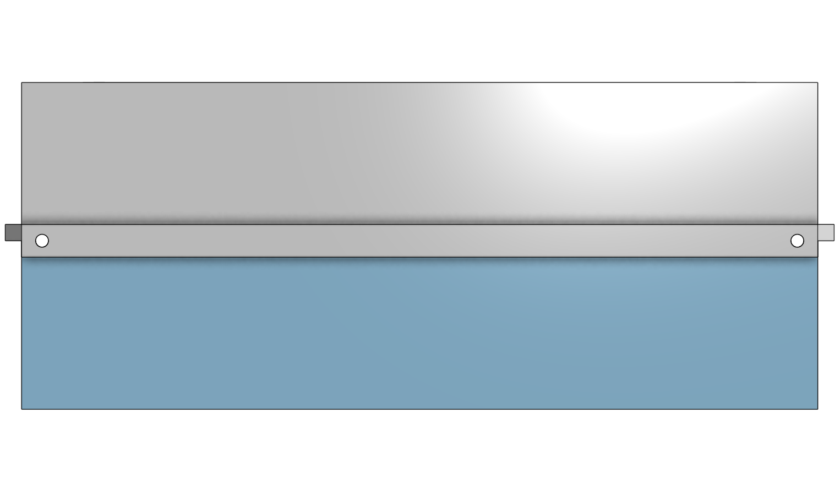
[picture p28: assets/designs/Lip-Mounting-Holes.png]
Lip Mounting Holes


on the mounting rails to keep the Pi in place,

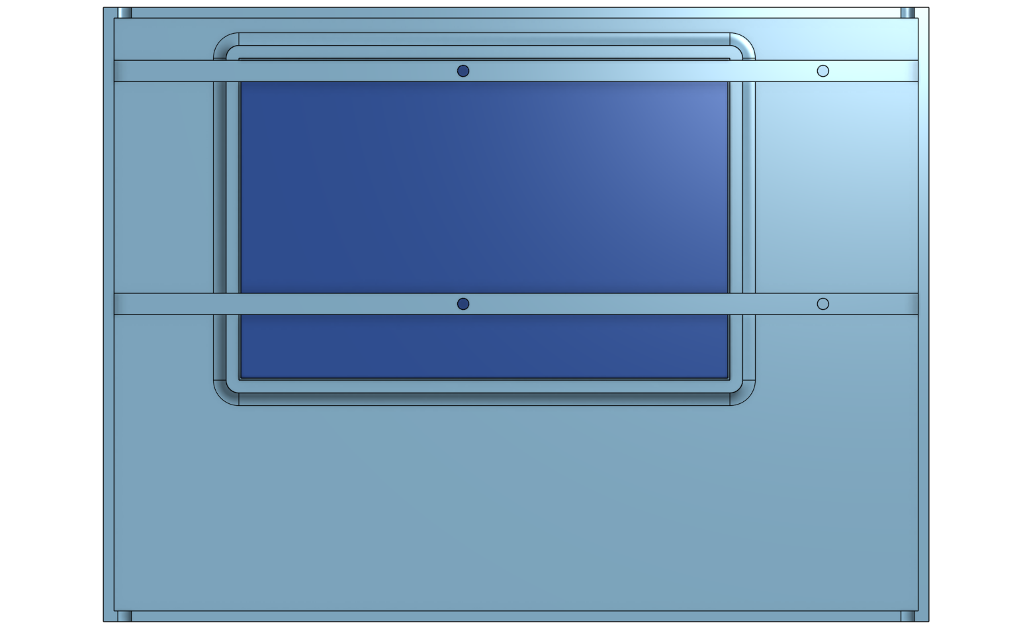
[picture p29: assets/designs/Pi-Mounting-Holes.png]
Pi Mounting Holes


and on the corners of the display cutout to mount the display in place.

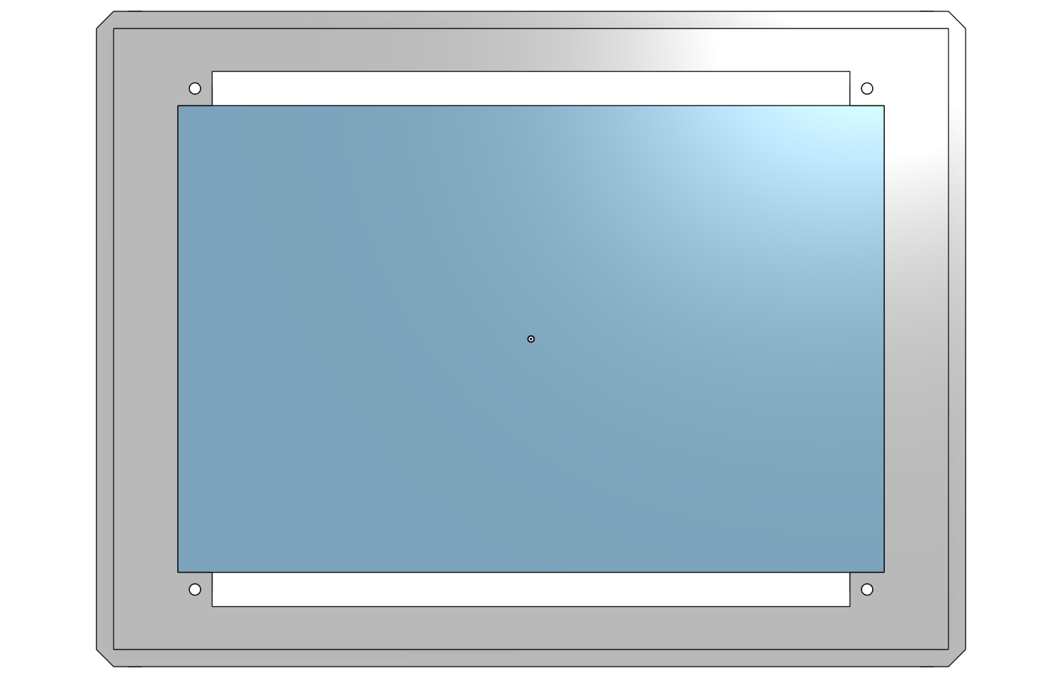
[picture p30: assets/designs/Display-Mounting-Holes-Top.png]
Display Mounting Holes (Top)


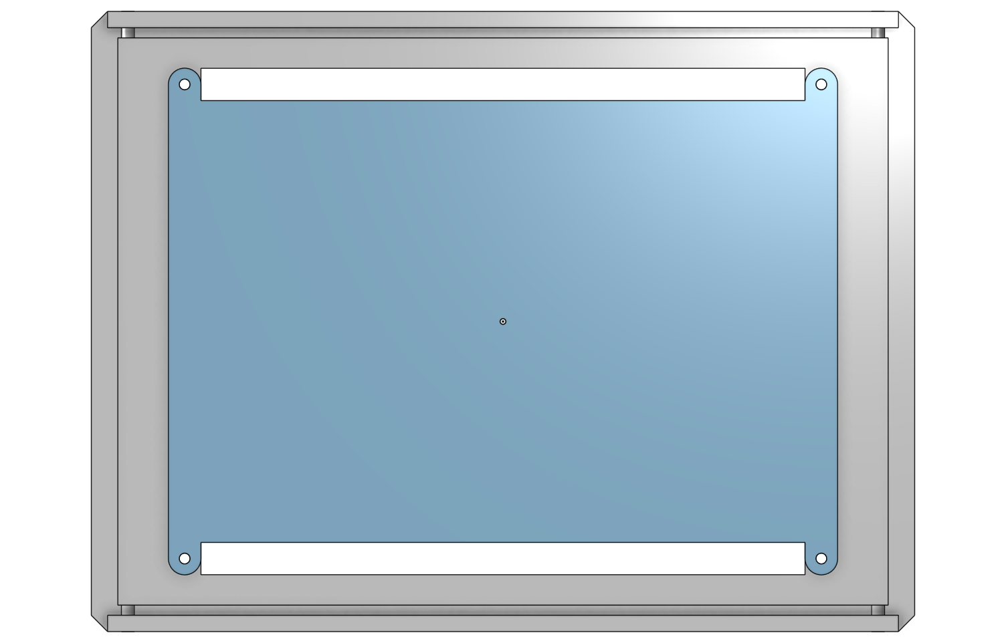
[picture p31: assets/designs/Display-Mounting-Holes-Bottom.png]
Display Mounting Holes (Bottom)


I used M2.5 holes for the Pi and display, along with M3 holes for the enclosure halves.

For documentation to work out later, I created two exploded views to tell the story of my assembly. The first one is a regular exploded view - showing the front, top, and side profiles - and another is a layered sort of exploded view - a front view of exploded parts that explains how every component is grouped and layered internally, which explains the tablet-like shape very well!

### Exploded View Part Numbers

1. Top Enclosure
2. Bottom Enclosure
3. Raspberry Pi
4. Battery Pack
5. Screen
6. Flash Drive
7. Alignment Lip
8. Battery Tray
9. Mounting Rails

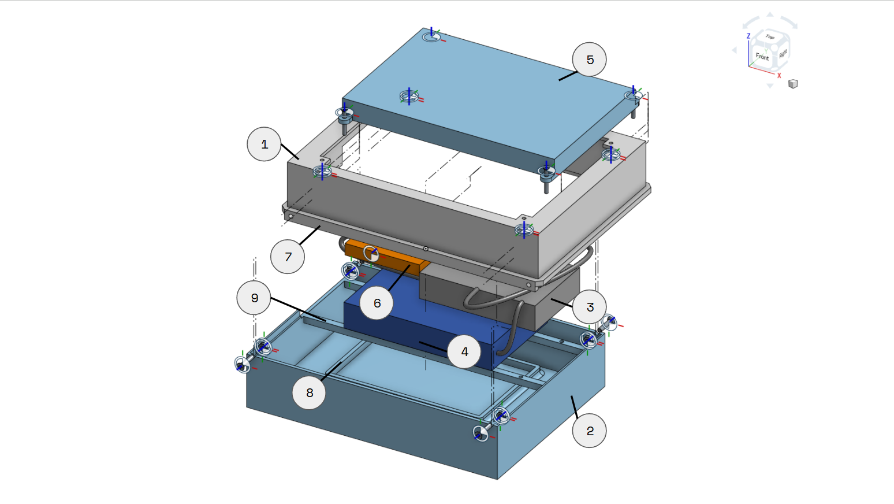
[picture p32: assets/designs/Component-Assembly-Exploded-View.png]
Exploded View (Total)


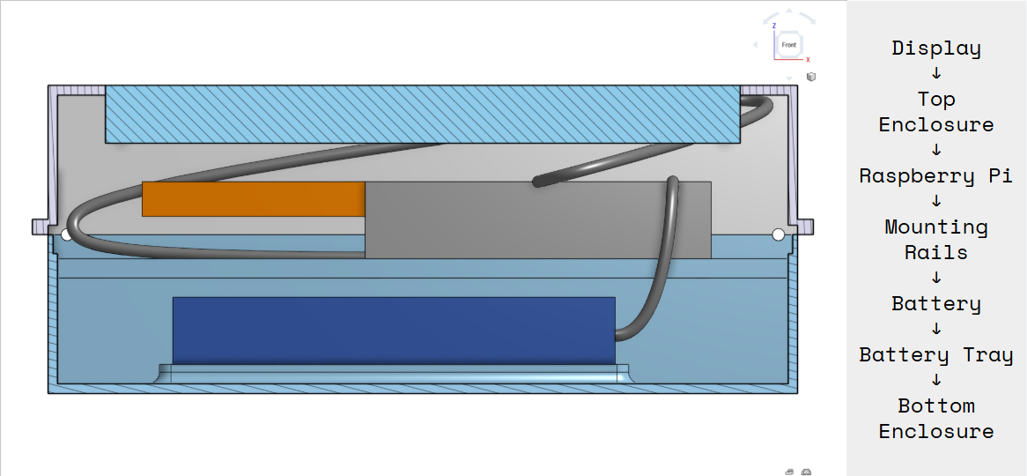
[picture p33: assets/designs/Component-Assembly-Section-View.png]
Exploded View (Layered/Section)


_TL;DR:_
- Added clearance holes to mount parts via screws and nuts later.
- Created two exploded assemblies (one a total assembly, another a layered assembly).

**Time Spent This Session: ~2 Hours**

## 2026-07-01

At this point, I was celebrating away. I started off with labeling my main exploded view, which made me realize just how much of my enclosure is truly done right now. I was surprised to find that all the components fit together in one enclosure, but when looking at the Pi in specific, I visualized the USB ports near where the flash drive was modeled. That's when I finally realized that the outside world still exists and I still need a way to connect external devices to the Pi when the enclosure is sealed off.

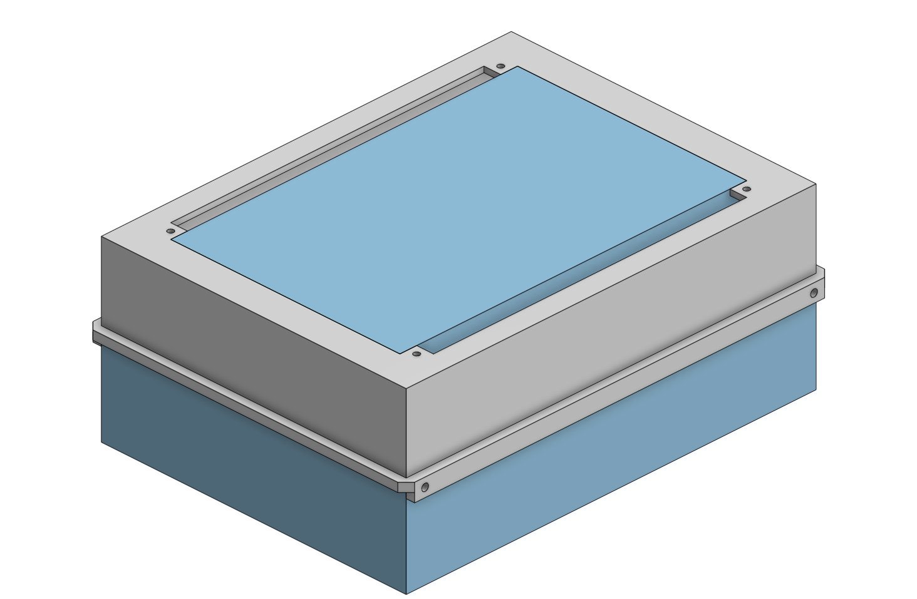
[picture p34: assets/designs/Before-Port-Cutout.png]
Before Port Cutout


This realization led to the creation of a side port cutout, which allows me to connect USB-based devices easily.

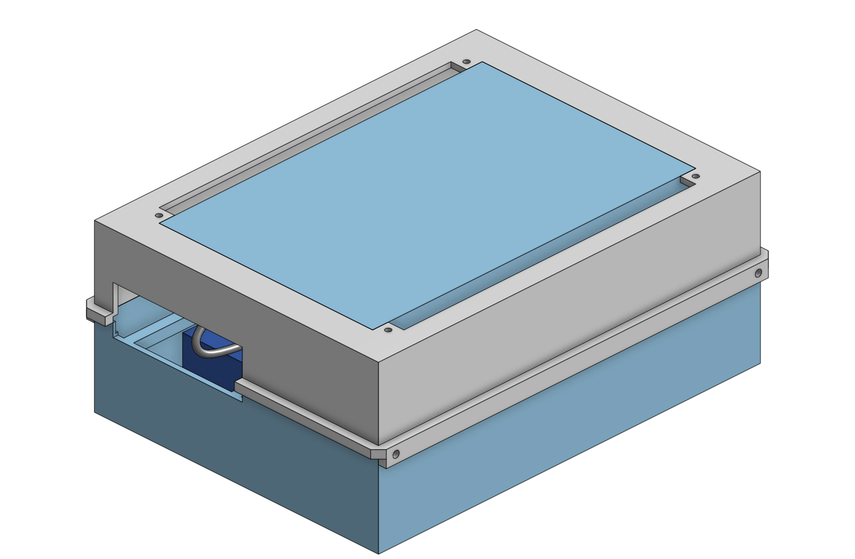
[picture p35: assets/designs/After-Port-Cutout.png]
After Port Cutout


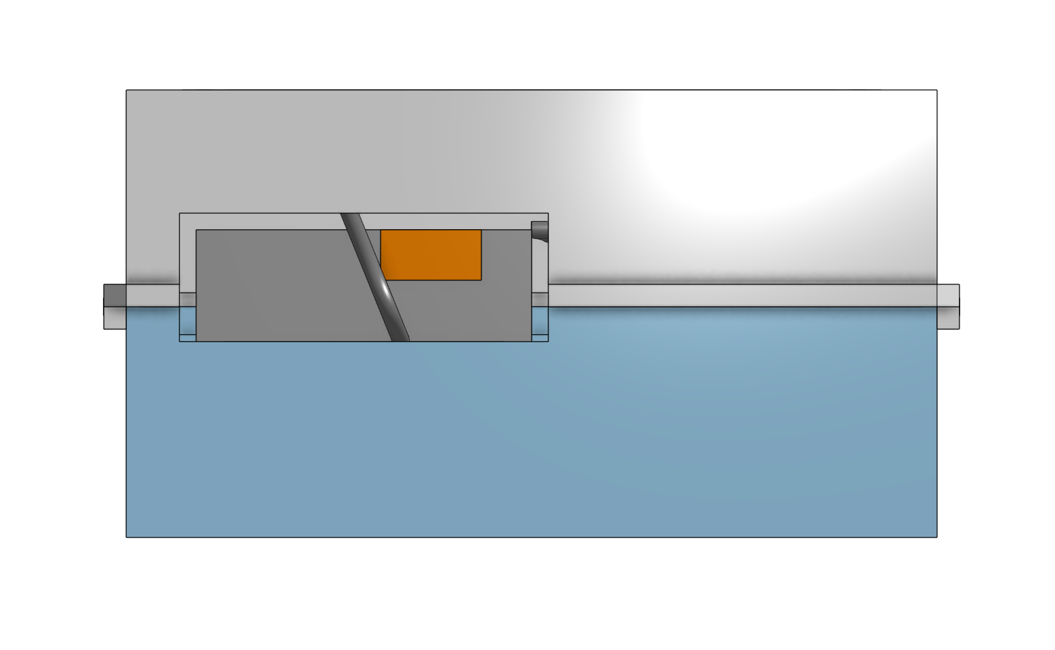
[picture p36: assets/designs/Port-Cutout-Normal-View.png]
Port Cutout (Normal View)


I updated my assembly documentation so that it was up to date with the project thus far - the cyberdeck was already planned out physically using a packaging study, and the wiring diagrams had every component interaction mapped out and planned.

All that was left to do was share this with Stardance with another devlog - and this one reflected more of the shaky, nonlinear path that took Stardeck to where it was. The time that I put into planning ahead of real-world constraints through digital means paid off in the end, and it reminded me why I build things such as Stardeck - to teach myself. Lots of engineering went through fitting the embedded systems together, and that showed. After posting my devlog, I also felt a real connection with the other builders on Stardance just by sharing what I had to demonstrate. I think that connection is what storytelling was meant to be. They've only been awarding points for storytelling (not merely "documentation") all along, which is how I learned that the best projects take others along for the ride.

_TL;DR:_
- Realized external USB ports would be inaccessible.
- Added side port cutout.
- Updated assembly documentation.
- Posted Devlog #2 to Stardance.

**Time Spent This Session: ~2.5 Hours**

## 2026-07-15

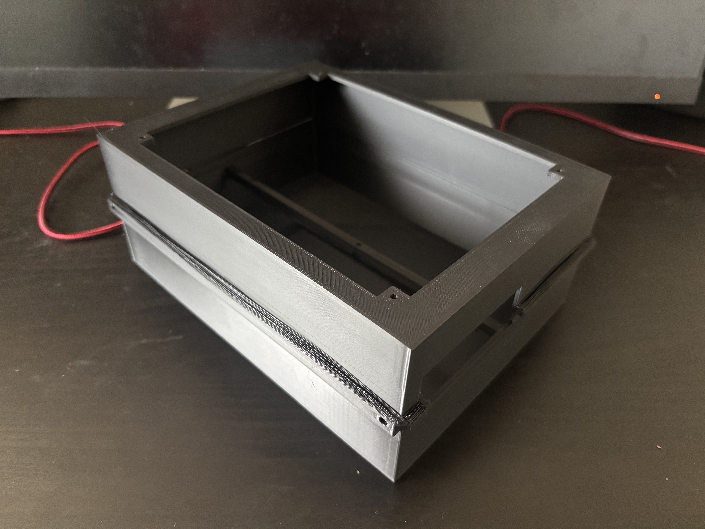
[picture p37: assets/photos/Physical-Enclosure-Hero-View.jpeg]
Physical Enclosure


Today, I held Stardeck's 3D-printed enclosure for the first time. Although I don't have the electronics yet, the enclosure already gives me a starting point for thinking about how every physical component should fit into Stardeck. I went with some trusty black PLA so that the enclosure can be focused on structural integrity before going for rework and aesthetic goals. I printed each enclosure half separately - one for the top, another for the bottom - and I'm surprised at how well it turned out for the first print. It's quite strange to see something existing and holdable in the real world when all I've been doing with it for weeks was rotating and clicking it in Onshape.

Tree supports worked surprisingly well at holding up overhangs, and they could pop right off unintrusively after the print finished. You can see the properties of the Onshape model in the physical enclosure, such as the display mounting area,

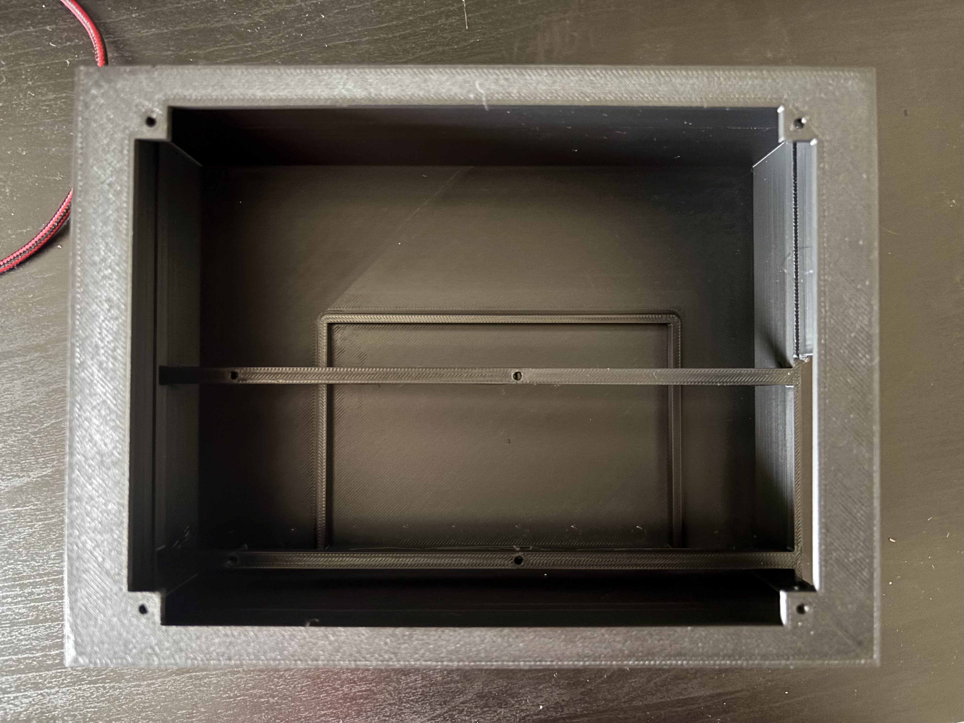
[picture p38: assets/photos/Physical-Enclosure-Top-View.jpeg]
Top View


the alignment lips,

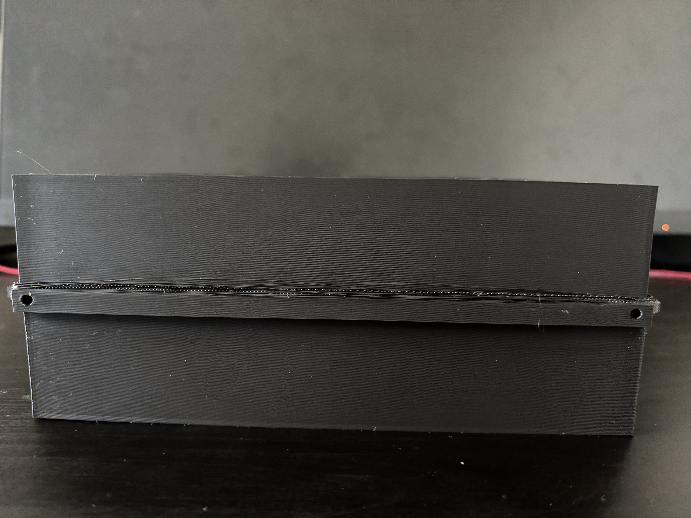
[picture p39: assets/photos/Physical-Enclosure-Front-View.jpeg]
Front View


and the USB port cutout.

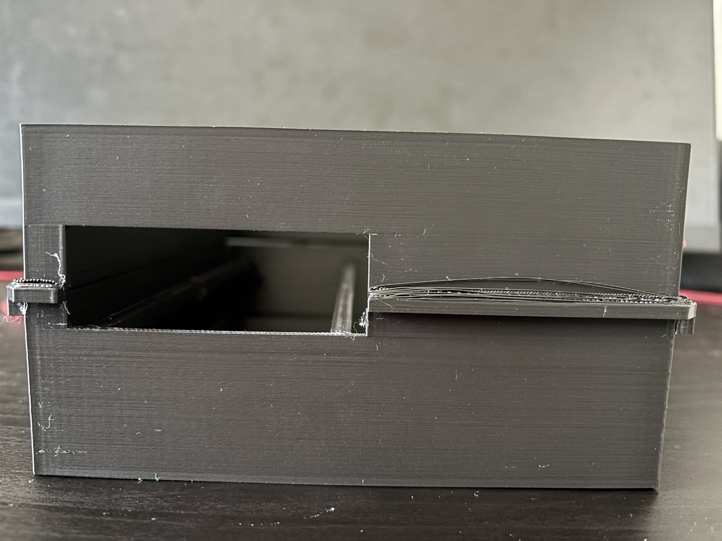
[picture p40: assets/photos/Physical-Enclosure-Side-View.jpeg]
Side View


Strands of filament seemed to be loosening and fringing off their respective surfaces on each half, which seemed like a design integrity issue at first. After looking into it online, I learned that it was a classic case of stringing in my print, not a structural problem. I had gotten lucky at this time since most of it was gathered near the tree supports - especially those holding up the mounting rails - and they were taken out when I snapped the supports off. I cut off any leftover pieces of stuck-out filament with a valuable new nuance of 3D prints in mind.

Seeing the two halves together also validated one of my earliest design decisions. The clamshell enclosure assembled exactly how I had hoped, making the design feel both practical and surprisingly satisfying to put together.

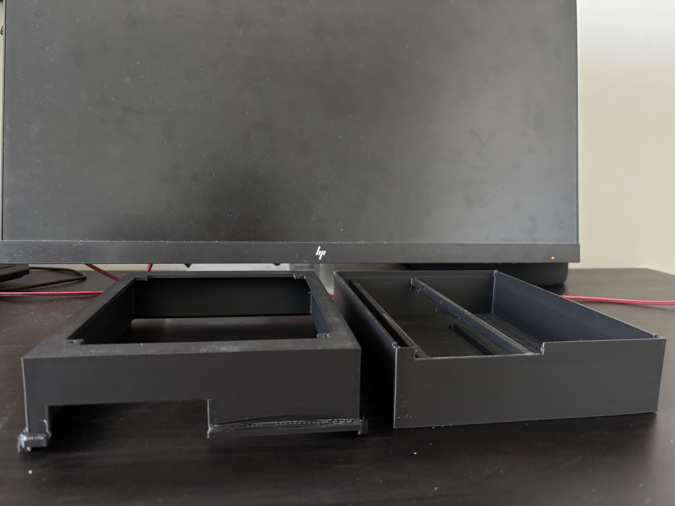
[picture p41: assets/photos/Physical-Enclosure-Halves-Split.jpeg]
Split Halves


With all this, I'll be sure to test out how screws fit in as well. When measuring each mounting hole, I found that printer tolerances had been in my favor this time as each diameter turned out to work with my plan. The M2.5 clearance holes held their modeled dimensions, and the M3 clearance holes for the enclosure halves added security as long as the enclosure halves are aligned via their alignment lips.

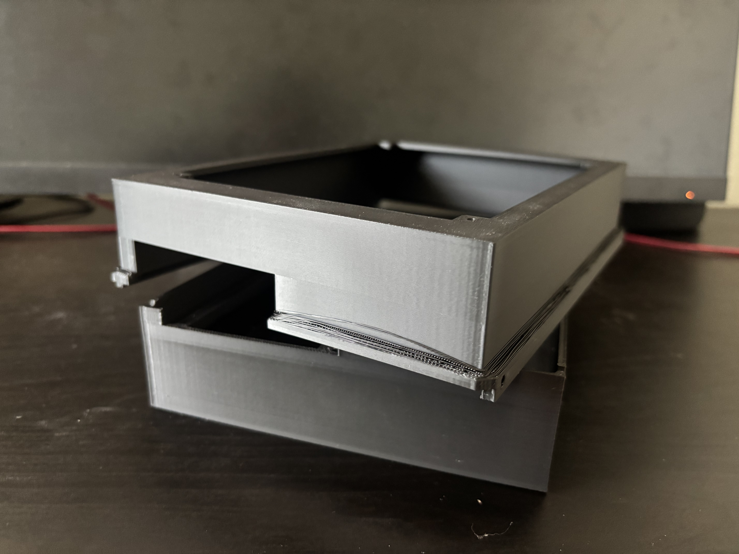
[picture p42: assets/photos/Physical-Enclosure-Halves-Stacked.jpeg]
Stacked Halves


I'm excited to see where Stardeck goes from here. You can only go so far with the most intricate of ideas, but it'll only be a thought unless you make it real. The first tangible milestone of the project taught me something cool: the design thinking you do before physical testing really does matter and really can save time, just as it saved me from wasting filament. I prepared to share this by drafting another Stardance devlog - #3 so far - and held my design decisions in my hands for the first time.

I was working through multiple sessions before this where I would refine documentation, polish the JOURNAL you're reading right now, and document my Onshape document using screenshots, too. During the "show-and-tell" phase, I realized at some point that I was no longer building on top of an idea, or exclusively thinking "what if?" I was navigating toward tangibility, which is where ideation meets practice.

_TL;DR:_
- Sliced and printed both enclosure halves via black PLA.
- Evaluated mounting hole sizes.
- Drafted Devlog #3 of Stardance.
- Refined documentation inside the repository.

**Time Spent This Session: ~7.5 Hours (including documentation completed across multiple work sessions)**

## Design Decisions

The following design decisions impacted the long-term path that Stardeck followed. This doesn't necessarily mean that they were the hardest to make, but it means that designs following these decisions were impacted by these sets of decisions making.

(More detailed coverage of the initial schematics and architecture maps used during the planning phase can be found in [`docs/initial_schematic.md`](docs/initial_schematic.md).)

1. Enclosure Structure

During the CAD process, I realized that modeling parts inside an enclosure is useless if the enclosure cannot open and close. This was the base idea for the USB port issue mentioned before, and it led to a choice between different types of closure methods:

- Back Panel: This would be similar to opening a computer case. One back panel can be unscrewed, giving you access to internals. When you're done, simply reinstall the back plate. This was an enticing option for its simplicity and reliability. Even the PC I'm using right now probably implements a back panel layout.

- Snap Fit: This seemed like the flashiest option. I realized, however, that printer tolerances would make a trivial feature of the enclosure that much harder to replicate and I wanted a method that would work over and over. Snap fits always seem like fun and games until your printer tolerances don't want to play.

- Clamshell: This is what I ended up going with. The top shell and bottom shell are two halves of the same, clam-like enclosure, and it allowed me to have the best command over internals. This won out over the back panel design because I could add, modify, and swap out components using angles from more than one face, which promised a higher likelihood of a successful assembly. Overall, this hit the sweet spot between being too fragmented and abstracting away important constraints.

Starter Clamshell

2. Mounting the Raspberry Pi

My initial placeholder assembly, which didn't account for every component, led me to initially bring the Pi above the battery inside the model. However, there had to be a way for the Pi to stay up there, since parts can't levitate in real life just because they can levitate in Onshape. I had to make a choice here, too.

- Corner Standoffs: These would basically act as poles that hold up the Pi by the corners. When I was modeling this in relation to other parts, however, this didn't work because some poles would be standing in the battery tray's space, which interferes with the battery. I was back to the drawing board as I had to think of something else.

- Floor Plate: The idea for this would be that the Pi would have a floor for it to rest on top of near the middle of the enclosure's height, sort of like a mezzanine or a tab that covers some of the bottom shell's view of the inside top shell looking up. However, this would interfere with the assembly later on - not the components, but the wiring. Generally speaking, the more internal obstacles and parts you add inside of an enclosure like the one I had, the less viable paths there are for wires to travel through. What we needed had to be a reliable mix of usability and efficiency, and I eventually found a mounting strategy that seemed strong.

- Mounting Rails: These fulfilled the task of holding the Pi up while also promising a simple yet elegant design that can work around other parts. With rails holding the Pi up, I was able to design cable routes that worked and had enough buffer to work around other paths if necessary. The rails also had a certain thickness to them that made it possible to truly mount the Pi in place using M2.5 screws inserted into clearance holes in the rails. Adding mounting rails was the most efficient working solution I could come up with, and I'm seeing how much time and energy I saved myself in the long run.

Mounting Rails

3. Mounting the Battery

The battery needed external support if it also wanted to be held up like the Pi. The battery I chose gave a good amount of power for such a manageable size, but there were many different ways to keep a battery from moving around too much.

- Mounting Straps: These seemed like the best long-term idea to me. It kept the battery in place (even when upside-down) and provided the most space-effective ways to keep the battery steady. However, these still were a very technical type of item to use for a minimum viable product, and so I turned this down for now.

- Battery Tray: This decision was made a lot quicker than my others, and I think the reason why is because I knew not to fix anything if it wasn't broken. A rectangle-shaped boundary gating allows the battery to stay in place without the need of buying more for something that can be solved using CAD. If the 0.5mm clearance I added for extra spacing on all sides causes the battery to move around unstably, I could always use a temporary solution like tape to make up for the clearance.

Battery Tray

## Lessons Learned

- Not only does CAD design parts, but it detects assembly-level problems before you do.
- If a mounting option is simple, that's probably the option you'll choose - not because complexity is bad, but because the simple solutions are the easiest to upkeep and monitor.
- Think about your physical assembly before printing, since you'll save LOTS of time later.
- Every design decision quietly changes three others, so weigh the pros and cons of what you do.

And finally:
- Software people can rock with hardware, too - just look at the intersection between software and hardware, demonstrated by Stardeck!

Hope you enjoyed reading the story Stardeck has to tell!

Signing off,
Yodahe

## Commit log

2026-06-16 Document initial system schematic via KiCAD
2026-06-16 Document packaging study as a part of initial schematic
2026-06-16 Refine initial schematic and packaging study documentation
2026-06-16 Add initial schema files to assets
    [Placeholder-Assembly.step, Placeholder-Assembly.stl, System-Schematic.kicad_sch]
2026-06-22 Add BOM as .csv file
    [BOM.csv]
2026-07-01 docs: update README with architecture, BOM, and roadmap
2026-07-01 Add Component Assembly files
    [Component-Assembly.step, Component-Assembly.stl]
2026-07-01 docs: update README with packaging study + polish
    [BOM.csv]
2026-07-16 docs: add enclosure models, photos, and print settings
    [Enclosure-Bottom.3mf, Enclosure-Bottom.step, Enclosure-Bottom.stl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]
2026-07-23 docs: add detail to existing printer settings
2026-08-18 docs: add screenshots of revised assembly for safekeeping
2026-08-24 docs: update BOM.csv to mention USD for Stardance review
    [BOM.csv]
2026-08-25 docs: add models of revised enclosure, top and bottom
    [Enclosure-Bottom-Revised.3mf, Enclosure-Bottom-Revised.step, Enclosure-Bottom-Revised.stl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]
2026-08-28 Revise folder structure for Stardance review
    [Component-Assembly.step, Component-Assembly.stl, Enclosure-Bottom-Revised.3mf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]
2026-09-02 Update BOM and System Architecture to reflect owning the Raspi
    [BOM.csv]
2026-09-30 Clarify requested funding and Raspi ownership for Stardance Review
    [BOM.csv]
